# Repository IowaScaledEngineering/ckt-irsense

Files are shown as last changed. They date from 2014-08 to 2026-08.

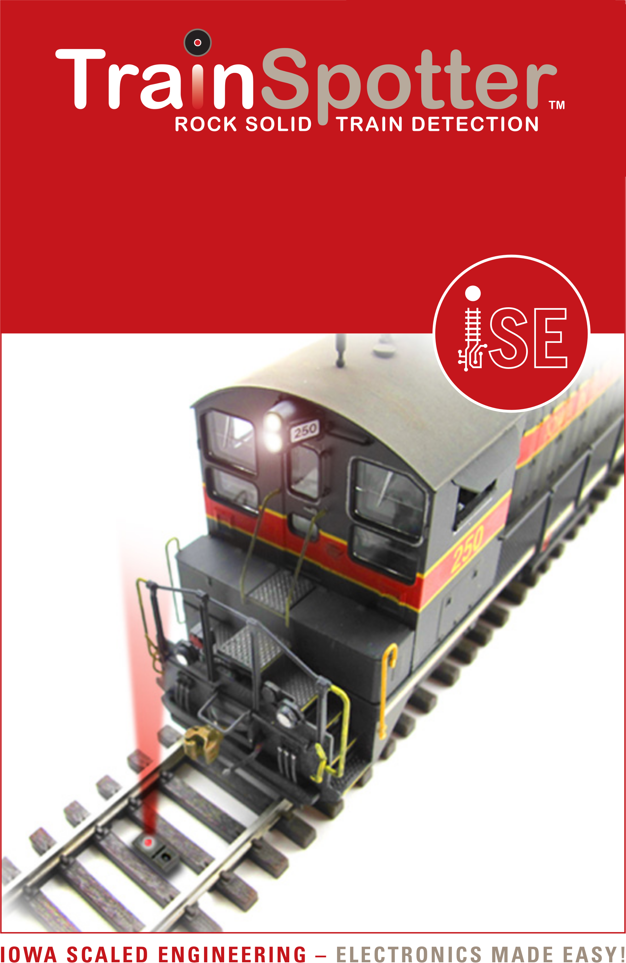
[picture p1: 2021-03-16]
doc/insert/irsense-insert.png

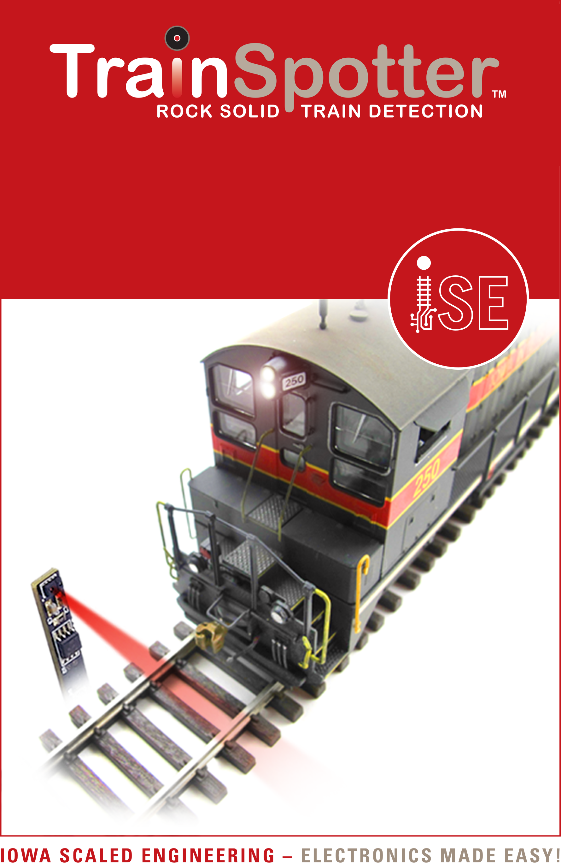
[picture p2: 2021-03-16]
doc/insert/irsense-insert-ra.png

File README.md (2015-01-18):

This is the software library, example applications, and hardware design files for the Iowa Scaled Engineering CKT-IRSENSE Reflective Infrared Proximity Sensor

The product can be found at:
http://www.iascaled.com/store/CKT-IRSENSE

Hardware use documentation (the manual) can be found in the /doc/ directory.

Like all public Iowa Scaled Engineering designs, the CKT-IRSENSE is both open hardware and open source software.  Please refer to the hardware and software license files in this repository for details.

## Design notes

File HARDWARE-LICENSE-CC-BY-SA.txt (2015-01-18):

The hardware design files for the Iowa Scaled Engineering CKT-IRSENSE are
open hardware, and licensed under the Creative Commons Attribution-Share
Alike license.

A copy can be found below, or from 
  http://creativecommons.org/licenses/by-sa/4.0/legalcode
-----------------------------------------------------------------------------

Creative Commons Attribution-ShareAlike 4.0 International Public License

By exercising the Licensed Rights (defined below), You accept and agree to
be bound by the terms and conditions of this Creative Commons
Attribution-ShareAlike 4.0 International Public License ("Public License").
To the extent this Public License may be interpreted as a contract, You are
granted the Licensed Rights in consideration of Your acceptance of these
terms and conditions, and the Licensor grants You such rights in
consideration of benefits the Licensor receives from making the Licensed
Material available under these terms and conditions.

Section 1 – Definitions.

    Adapted Material means material subject to Copyright and Similar Rights
that is derived from or based upon the Licensed Material and in which the
Licensed Material is translated, altered, arranged, transformed, or
otherwise modified in a manner requiring permission under the Copyright and
Similar Rights held by the Licensor. For purposes of this Public License,
where the Licensed Material is a musical work, performance, or sound
recording, Adapted Material is always produced where the Licensed Material
is synched in timed relation with a moving image.
    Adapter's License means the license You apply to Your Copyright and
Similar Rights in Your contributions to Adapted Material in accordance with
the terms and conditions of this Public License.
    BY-SA Compatible License means a license listed at
creativecommons.org/compatiblelicenses, approved by Creative Commons as
essentially the equivalent of this Public License.
    Copyright and Similar Rights means copyright and/or similar rights
closely related to copyright including, without limitation, performance,
broadcast, sound recording, and Sui Generis Database Rights, without regard
to how the rights are labeled or categorized. For purposes of this Public
License, the rights specified in Section 2(b)(1)-(2) are not Copyright and
Similar Rights.
    Effective Technological Measures means those measures that, in the
absence of proper authority, may not be circumvented under laws fulfilling
obligations under Article 11 of the WIPO Copyright Treaty adopted on
December 20, 1996, and/or similar international agreements.
    Exceptions and Limitations means fair use, fair dealing, and/or any
other exception or limitation to Copyright and Similar Rights that applies
to Your use of the Licensed Material.
    License Elements means the license attributes listed in the name of a
Creative Commons Public License. The License Elements of this Public License
are Attribution and ShareAlike.
    Licensed Material means the artistic or literary work, database, or
other material to which the Licensor applied this Public License.
    Licensed Rights means the rights granted to You subject to the terms and
conditions of this Public License, which are limited to all Copyright and
Similar Rights that apply to Your use of the Licensed Material and that the
Licensor has authority to license.
    Licensor means the individual(s) or entity(ies) granting rights under
this Public License.
    Share means to provide material to the public by any means or process
that requires permission under the Licensed Rights, such as reproduction,
public display, public performance, distribution, dissemination,
communication, or importation, and to make material available to the public
including in ways that members of the public may access the material from a
place and at a time individually chosen by them.
    Sui Generis Database Rights means rights other than copyright resulting
from Directive 96/9/EC of the European Parliament and of the Council of 11
March 1996 on the legal protection of databases, as amended and/or
succeeded, as well as other essentially equivalent rights anywhere in the
world.
    You means the individual or entity exercising the Licensed Rights under
this Public License. Your has a corresponding meaning.

Section 2 – Scope.

    License grant.
        Subject to the terms and conditions of this Public License, the
Licensor hereby grants You a worldwide, royalty-free, non-sublicensable,
non-exclusive, irrevocable license to exercise the Licensed Rights in the
Licensed Material to:
            reproduce and Share the Licensed Material, in whole or in part;
and
            produce, reproduce, and Share Adapted Material.
        Exceptions and Limitations. For the avoidance of doubt, where
Exceptions and Limitations apply to Your use, this Public License does not
apply, and You do not need to comply with its terms and conditions.
        Term. The term of this Public License is specified in Section 6(a).
        Media and formats; technical modifications allowed. The Licensor
authorizes You to exercise the Licensed Rights in all media and formats
whether now known or hereafter created, and to make technical modifications
necessary to do so. The Licensor waives and/or agrees not to assert any
right or authority to forbid You from making technical modifications
necessary to exercise the Licensed Rights, including technical modifications
necessary to circumvent Effective Technological Measures. For purposes of
this Public License, simply making modifications authorized by this Section
2(a)(4) never produces Adapted Material.
        Downstream recipients.
            Offer from the Licensor – Licensed Material. Every recipient of
the Licensed Material automatically receives an offer from the Licensor to
exercise the Licensed Rights under the terms and conditions of this Public
License.
            Additional offer from the Licensor – Adapted Material. Every
recipient of Adapted Material from You automatically receives an offer from
the Licensor to exercise the Licensed Rights in the Adapted Material under
the conditions of the Adapter’s License You apply.
            No downstream restrictions. You may not offer or impose any
additional or different terms or conditions on, or apply any Effective
Technological Measures to, the Licensed Material if doing so restricts
exercise of the Licensed Rights by any recipient of the Licensed Material.
        No endorsement. Nothing in this Public License constitutes or may be
construed as permission to assert or imply that You are, or that Your use of
the Licensed Material is, connected with, or sponsored, endorsed, or granted
official status by, the Licensor or others designated to receive attribution
as provided in Section 3(a)(1)(A)(i).

    Other rights.
        Moral rights, such as the right of integrity, are not licensed under
this Public License, nor are publicity, privacy, and/or other similar
personality rights; however, to the extent possible, the Licensor waives
and/or agrees not to assert any such rights held by the Licensor to the
limited extent necessary to allow You to exercise the Licensed Rights, but
not otherwise.
        Patent and trademark rights are not licensed under this Public
License.
        To the extent possible, the Licensor waives any right to collect
royalties from You for the exercise of the Licensed Rights, whether directly
or through a collecting society under any voluntary or waivable statutory or
compulsory licensing scheme. In all other cases the Licensor expressly
reserves any right to collect such royalties.

Section 3 – License Conditions.

Your exercise of the Licensed Rights is expressly made subject to the
following conditions.

    Attribution.

        If You Share the Licensed Material (including in modified form), You
must:
            retain the following if it is supplied by the Licensor with the
Licensed Material:
                identification of the creator(s) of the Licensed Material
and any others designated to receive attribution, in any reasonable manner
requested by the Licensor (including by pseudonym if designated);
                a copyright notice;
                a notice that refers to this Public License;
                a notice that refers to the disclaimer of warranties;
                a URI or hyperlink to the Licensed Material to the extent
                reasonably practicable;
            indicate if You modified the Licensed Material and retain an
indication of any previous modifications; and
            indicate the Licensed Material is licensed under this Public
License, and include the text of, or the URI or hyperlink to, this Public
License.
        You may satisfy the conditions in Section 3(a)(1) in any reasonable
manner based on the medium, means, and context in which You Share the
Licensed Material. For example, it may be reasonable to satisfy the
conditions by providing a URI or hyperlink to a resource that includes the
required information.
        If requested by the Licensor, You must remove any of the information
required by Section 3(a)(1)(A) to the extent reasonably practicable.
    ShareAlike.

    In addition to the conditions in Section 3(a), if You Share Adapted
Material You produce, the following conditions also apply.
        The Adapter’s License You apply must be a Creative Commons license
with the same License Elements, this version or later, or a BY-SA Compatible
License.
        You must include the text of, or the URI or hyperlink to, the
Adapter's License You apply. You may satisfy this condition in any
reasonable manner based on the medium, means, and context in which You Share
Adapted Material.
        You may not offer or impose any additional or different terms or
conditions on, or apply any Effective Technological Measures to, Adapted
Material that restrict exercise of the rights granted under the Adapter's
License You apply.

Section 4 – Sui Generis Database Rights.

Where the Licensed Rights include Sui Generis Database Rights that apply to
Your use of the Licensed Material:

    for the avoidance of doubt, Section 2(a)(1) grants You the right to
extract, reuse, reproduce, and Share all or a substantial portion of the
contents of the database;
    if You include all or a substantial portion of the database contents in
a database in which You have Sui Generis Database Rights, then the database
in which You have Sui Generis Database Rights (but not its individual
contents) is Adapted Material, including for purposes of Section 3(b); and
    You must comply with the conditions in Section 3(a) if You Share all or
a substantial portion of the contents of the database.

For the avoidance of doubt, this Section 4 supplements and does not replace
Your obligations under this Public License where the Licensed Rights include
other Copyright and Similar Rights.

Section 5 – Disclaimer of Warranties and Limitation of Liability.

    Unless otherwise separately undertaken by the Licensor, to the extent
possible, the Licensor offers the Licensed Material as-is and as-available,
and makes no representations or warranties of any kind concerning the
Licensed Material, whether express, implied, statutory, or other. This
includes, without limitation, warranties of title, merchantability, fitness
for a particular purpose, non-infringement, absence of latent or other
defects, accuracy, or the presence or absence of errors, whether or not
known or discoverable. Where disclaimers of warranties are not allowed in
full or in part, this disclaimer may not apply to You.
    To the extent possible, in no event will the Licensor be liable to You
on any legal theory (including, without limitation, negligence) or otherwise
for any direct, special, indirect, incidental, consequential, punitive,
exemplary, or other losses, costs, expenses, or damages arising out of this
Public License or use of the Licensed Material, even if the Licensor has
been advised of the possibility of such losses, costs, expenses, or damages.
Where a limitation of liability is not allowed in full or in part, this
limitation may not apply to You.

    The disclaimer of warranties and limitation of liability provided above
shall be interpreted in a manner that, to the extent possible, most closely
approximates an absolute disclaimer and waiver of all liability.

Section 6 – Term and Termination.

    This Public License applies for the term of the Copyright and Similar
Rights licensed here. However, if You fail to comply with this Public
License, then Your rights under this Public License terminate automatically.

    Where Your right to use the Licensed Material has terminated under
Section 6(a), it reinstates:
        automatically as of the date the violation is cured, provided it is
cured within 30 days of Your discovery of the violation; or
        upon express reinstatement by the Licensor.
    For the avoidance of doubt, this Section 6(b) does not affect any right
the Licensor may have to seek remedies for Your violations of this Public
License.
    For the avoidance of doubt, the Licensor may also offer the Licensed
Material under separate terms or conditions or stop distributing the
Licensed Material at any time; however, doing so will not terminate this
Public License.
    Sections 1, 5, 6, 7, and 8 survive termination of this Public License.

Section 7 – Other Terms and Conditions.

    The Licensor shall not be bound by any additional or different terms or
conditions communicated by You unless expressly agreed.
    Any arrangements, understandings, or agreements regarding the Licensed
Material not stated herein are separate from and independent of the terms
and conditions of this Public License.

Section 8 – Interpretation.

    For the avoidance of doubt, this Public License does not, and shall not
be interpreted to, reduce, limit, restrict, or impose conditions on any use
of the Licensed Material that could lawfully be made without permission
under this Public License.
    To the extent possible, if any provision of this Public License is
deemed unenforceable, it shall be automatically reformed to the minimum
extent necessary to make it enforceable. If the provision cannot be
reformed, it shall be severed from this Public License without affecting the
enforceability of the remaining terms and conditions.
    No term or condition of this Public License will be waived and no
failure to comply consented to unless expressly agreed to by the Licensor.
    Nothing in this Public License constitutes or may be interpreted as a
limitation upon, or waiver of, any privileges and immunities that apply to
the Licensor or You, including from the legal processes of any jurisdiction
or authority.

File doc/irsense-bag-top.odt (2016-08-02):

Iowa Scaled Engineering, LLC

http://iascaled.com/

Iowa Scaled Engineering, LLC

http://iascaled.com/

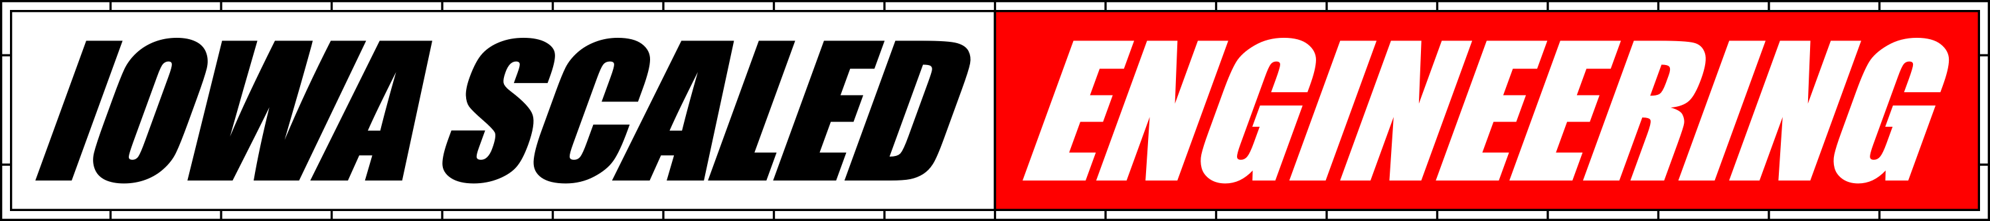
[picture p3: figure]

Reflective Infrared Proximity Sensor

The CKT-IRSENSE is an inexpensive reflective infrared proximity sensor, designed primarily for model railroad use, utilizing the latest in proximity sensor technology. It can be used to trigger a variety of sound and visual effects as well as provide track occupancy status.

CKT-IRSENSE

Reflective Infrared Proximity Sensor

The CKT-IRSENSE-2PC is an inexpensive reflective infrared proximity sensor, designed primarily for model railroad use, utilizing the latest in proximity sensor technology. It can be used to trigger a variety of sound and visual effects as well as provide track occupancy status. The sensor is connected via 4-conductor flat wire cable to the control board allowing greater flexibility in mounting the sensor.

CKT-IRSENSE-2PC

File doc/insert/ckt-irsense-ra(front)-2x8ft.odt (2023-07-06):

Reflective Infrared Proximity Sensor with Right-Angle Sensor

www.iascaled.com

2x CKT-IRSENSE-RA

With 8’ cables

Reflective Infrared Proximity Sensor with Right-Angle Sensor

www.iascaled.com

2x CKT-IRSENSE-RA

With 8’ cables

Reflective Infrared Proximity Sensor with Right-Angle Sensor

www.iascaled.com

2x CKT-IRSENSE-RA

With 8’ cables

Reflective Infrared Proximity Sensor with Right-Angle Sensor

www.iascaled.com

2x CKT-IRSENSE-RA

With 8’ cables

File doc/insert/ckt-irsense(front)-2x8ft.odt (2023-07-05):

Reflective Infrared Proximity Sensor

www.iascaled.com

2x CKT-IRSENSE

With 8’ cables

Reflective Infrared Proximity Sensor

www.iascaled.com

2x CKT-IRSENSE

With 8’ cables

Reflective Infrared Proximity Sensor

www.iascaled.com

2x CKT-IRSENSE

With 8’ cables

Reflective Infrared Proximity Sensor

www.iascaled.com

2x CKT-IRSENSE

With 8’ cables

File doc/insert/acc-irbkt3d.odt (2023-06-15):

IR Sensor Mounting Bracket Kit

www.iascaled.com

ACC-IRBKT3D

$4.00

IR Sensor Mounting Bracket Kit

www.iascaled.com

ACC-IRBKT3D

$4.00

IR Sensor Mounting Bracket Kit

www.iascaled.com

ACC-IRBKT3D

$4.00

IR Sensor Mounting Bracket Kit

www.iascaled.com

ACC-IRBKT3D

$4.00

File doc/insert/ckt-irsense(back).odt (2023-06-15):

The TrainSpotter is a simple infrared proximity sensor that makes detection of model railroad locomotives and rolling stock easy and reliable. Just place the sensor where its invisible light beam will reflect off the object of interest and you’re done – no time-consuming or frustrating adjustments! Based on modern silicon technology, this sensor is tolerant of ambient (background) lighting conditions, be it completely dark or under full lights, with no false triggering. With a discrete under-track installation, this low-profile sensor solves many of the challenges that plague other optical detector products.

Typical Applications

● Activate grade crossing signals

● Trigger sounds

● Build an automatic interchange

● Indicate end-of-track in hidden staging yards

● Detect block occupancy for signal systems

The TrainSpotter is a simple infrared proximity sensor that makes detection of model railroad locomotives and rolling stock easy and reliable. Just place the sensor where its invisible light beam will reflect off the object of interest and you’re done – no time-consuming or frustrating adjustments! Based on modern silicon technology, this sensor is tolerant of ambient (background) lighting conditions, be it completely dark or under full lights, with no false triggering. With a discrete under-track installation, this low-profile sensor solves many of the challenges that plague other optical detector products.

Typical Applications

● Activate grade crossing signals

● Trigger sounds

● Build an automatic interchange

● Indicate end-of-track in hidden staging yards

● Detect block occupancy for signal systems

The TrainSpotter is a simple infrared proximity sensor that makes detection of model railroad locomotives and rolling stock easy and reliable. Just place the sensor where its invisible light beam will reflect off the object of interest and you’re done – no time-consuming or frustrating adjustments! Based on modern silicon technology, this sensor is tolerant of ambient (background) lighting conditions, be it completely dark or under full lights, with no false triggering. With a discrete under-track installation, this low-profile sensor solves many of the challenges that plague other optical detector products.

Typical Applications

● Activate grade crossing signals

● Trigger sounds

● Build an automatic interchange

● Indicate end-of-track in hidden staging yards

● Detect block occupancy for signal systems

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

Typical Applications

● Activate grade crossing signals

● Trigger sounds

● Build an automatic interchange

● Indicate end-of-track in hidden staging yards

● Detect block occupancy for signal systems

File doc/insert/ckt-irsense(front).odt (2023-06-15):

Reflective Infrared Proximity Sensor

www.iascaled.com

CKT-IRSENSE

$19.00

Reflective Infrared Proximity Sensor

www.iascaled.com

CKT-IRSENSE

$19.00

Reflective Infrared Proximity Sensor

www.iascaled.com

CKT-IRSENSE

$19.00

Reflective Infrared Proximity Sensor

www.iascaled.com

CKT-IRSENSE

$19.00

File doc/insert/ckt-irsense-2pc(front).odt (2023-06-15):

Reflective Infrared Proximity Sensor with Remote Sensor

www.iascaled.com

CKT-IRSENSE-2PC

$25.00

Reflective Infrared Proximity Sensor with Remote Sensor

www.iascaled.com

CKT-IRSENSE-2PC

$25.00

Reflective Infrared Proximity Sensor with Remote Sensor

www.iascaled.com

CKT-IRSENSE-2PC

$25.00

Reflective Infrared Proximity Sensor with Remote Sensor

www.iascaled.com

CKT-IRSENSE-2PC

$25.00

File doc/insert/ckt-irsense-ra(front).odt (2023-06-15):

Reflective Infrared Proximity Sensor with Right-Angle Sensor

www.iascaled.com

CKT-IRSENSE-RA

$19.00

Reflective Infrared Proximity Sensor with Right-Angle Sensor

www.iascaled.com

CKT-IRSENSE-RA

$19.00

Reflective Infrared Proximity Sensor with Right-Angle Sensor

www.iascaled.com

CKT-IRSENSE-RA

$19.00

Reflective Infrared Proximity Sensor with Right-Angle Sensor

www.iascaled.com

CKT-IRSENSE-RA

$19.00

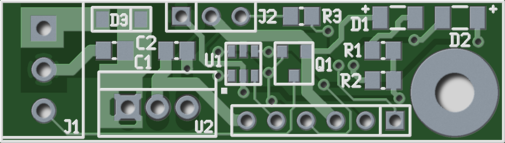
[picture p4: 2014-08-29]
doc/applications/spring-switch/mrservo.png

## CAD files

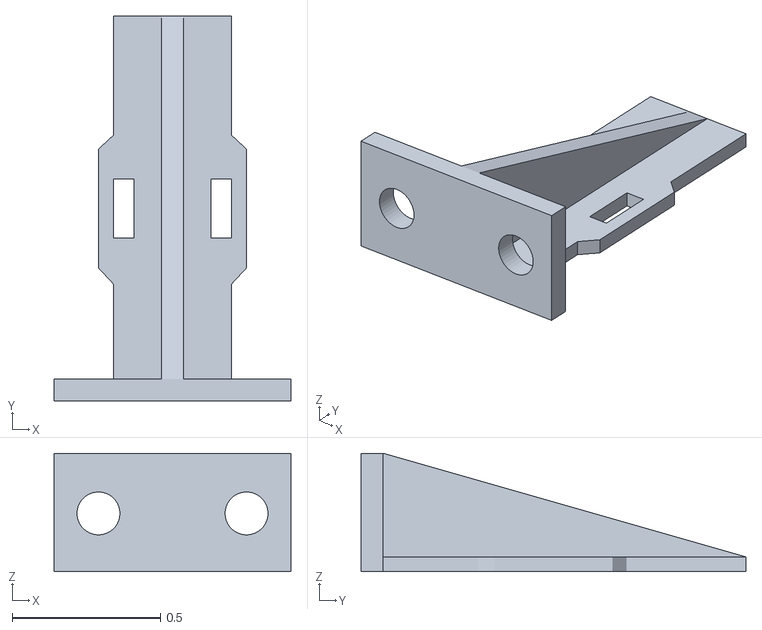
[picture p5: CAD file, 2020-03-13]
mech/irsense-bracket/irsense-bracket v2.stl
0.8 x 1.30 x 0.4

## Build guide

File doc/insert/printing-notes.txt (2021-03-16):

IRSENSE INSERT
--------------
Print settings (M475):
- Print PDF from Acrobat
- Use "Photo (sRGB)" color theme

Print Settings (8210)
- Print from libreoffice
- Maximum DPI
- HP Brochure Matte 180g
- Default (sRGB)

10/25/2020: "Yellowed" images to get better color rendition on printer
10/30/2020: Reverted to original images

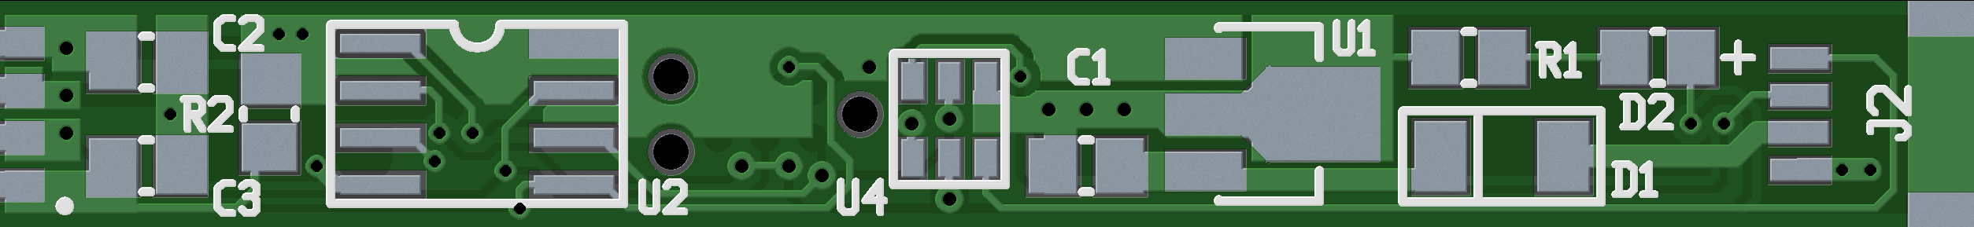
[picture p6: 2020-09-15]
doc/usermanual/ckt-irsense-front.png

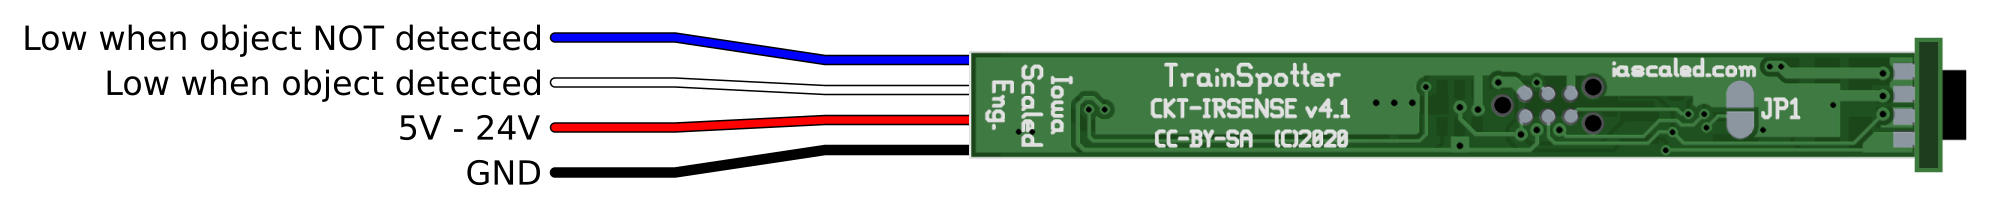
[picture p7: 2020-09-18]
doc/usermanual/usermanual.png

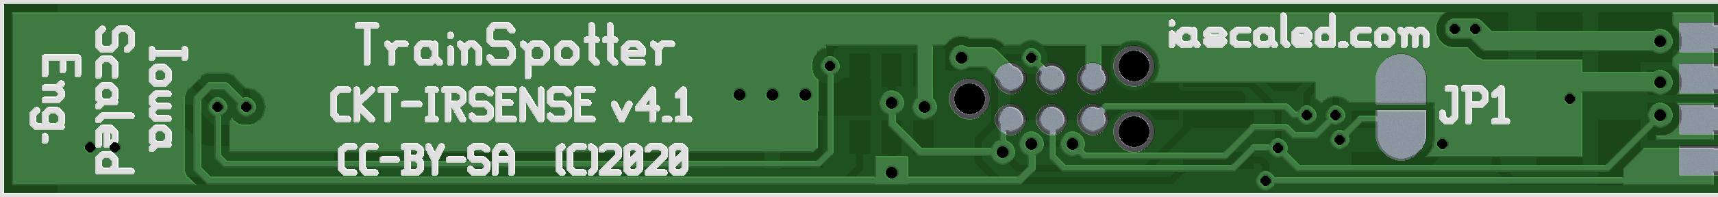
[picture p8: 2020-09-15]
doc/usermanual/ckt-irsense-back.png

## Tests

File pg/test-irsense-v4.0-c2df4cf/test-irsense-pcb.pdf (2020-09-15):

# test-irsense.pcb

# 1. Table of Contents (This Page) Created on Wed Aug 19 21:00:15 2020

# 2. top 3. bottom 4. plated-drill 5. componentmask 6. soldermask 7. topsilk 8. bottomsilk 9. toppaste 10. topassembly 11. bottomassembly 12. fab

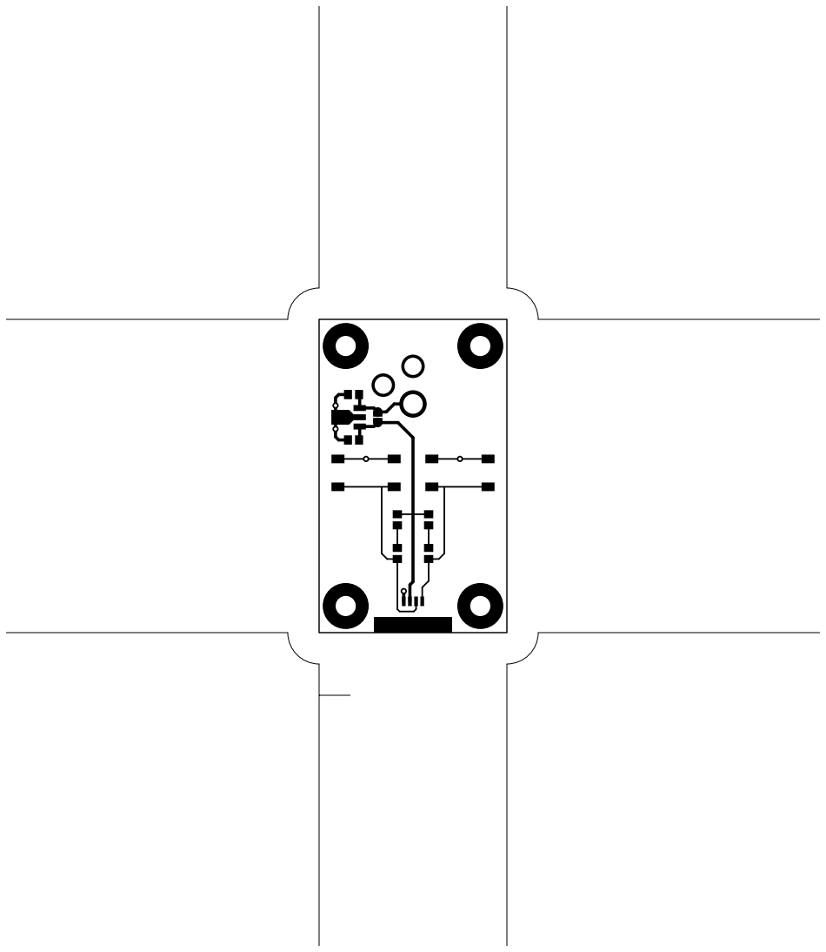
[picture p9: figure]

top, scale = 1:1.000

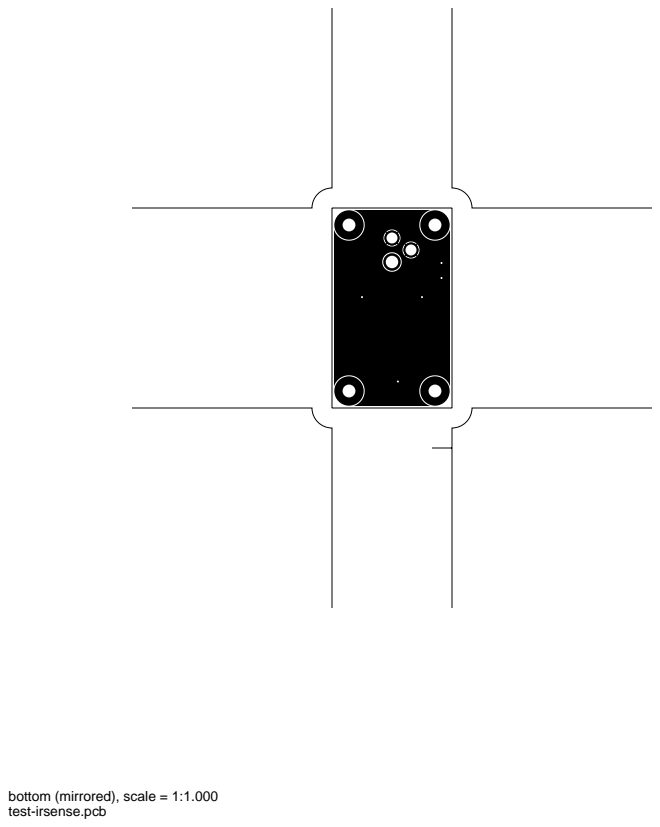
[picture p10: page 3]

bottom (mirrored), scale = 1:1.000

plated-drill, scale = 1:1.000

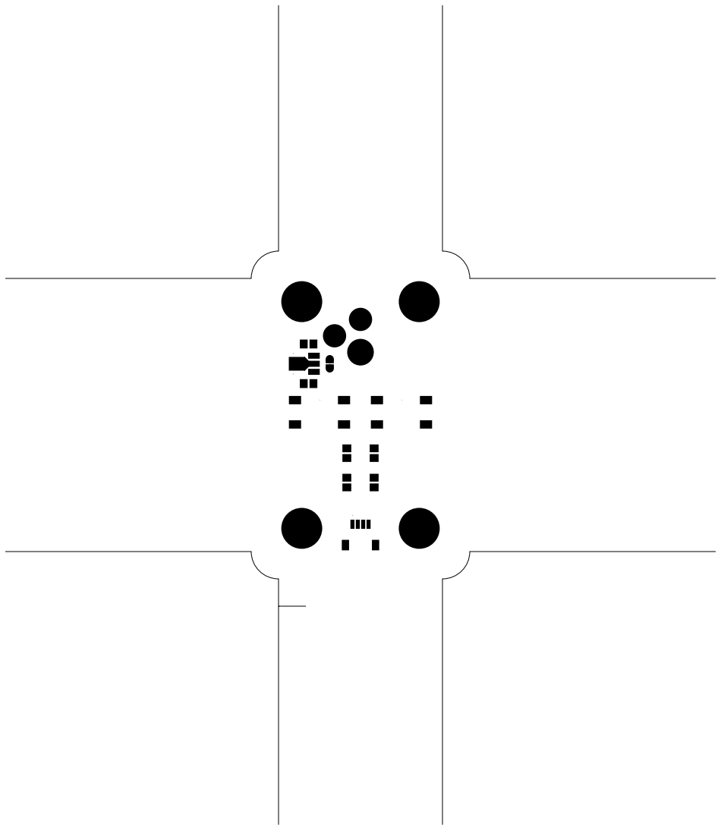
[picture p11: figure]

topmask, scale = 1:1.000

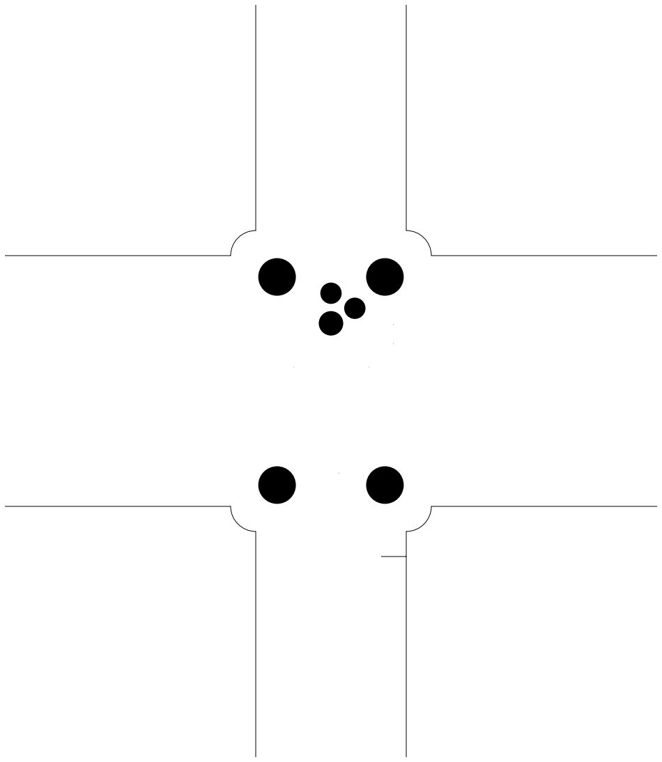
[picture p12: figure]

bottommask (mirrored), scale = 1:1.000

topsilk, scale = 1:1.000 bottomsilk (mirrored), scale = 1:1.000

toppaste, scale = 1:1.000

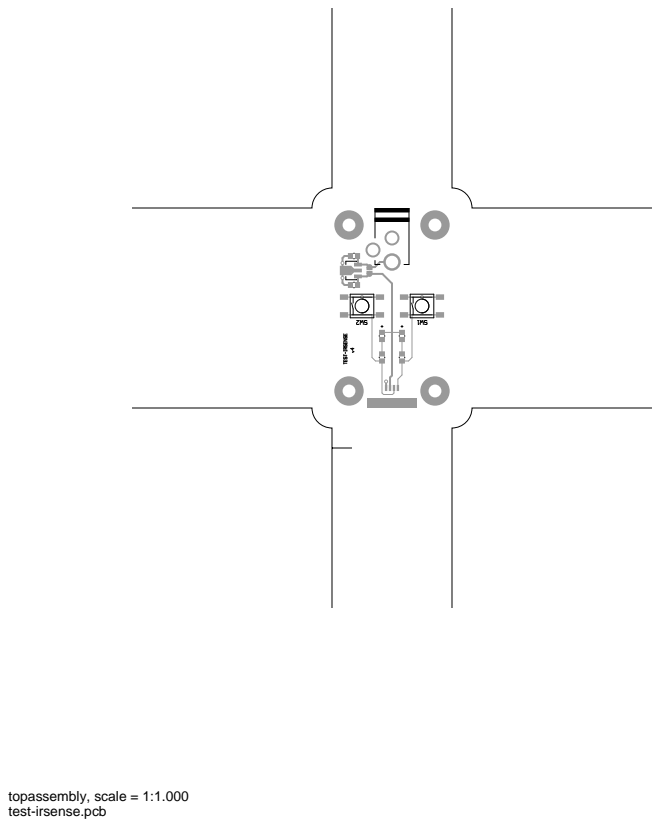
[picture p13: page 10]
topassembly, scale = 1:1.000

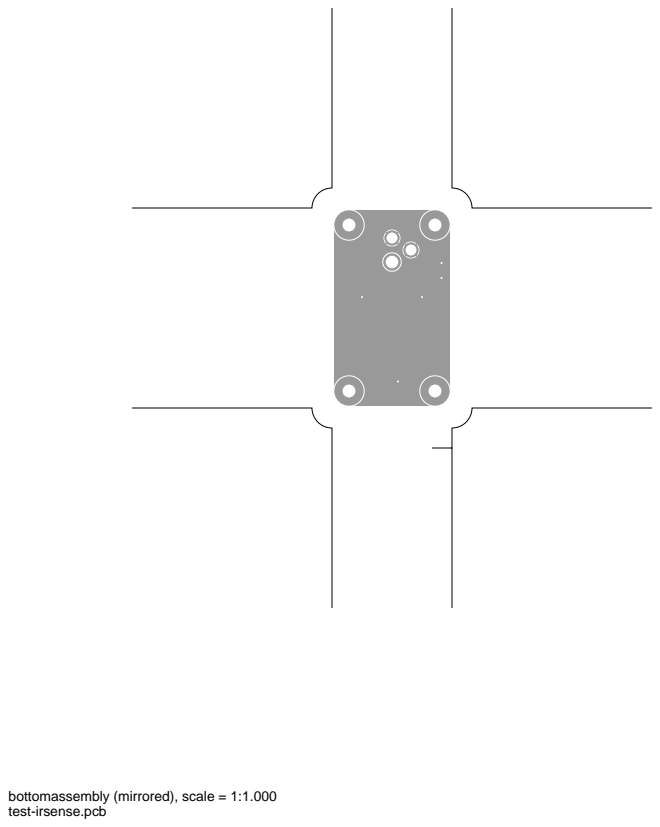
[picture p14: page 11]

bottomassembly (mirrored), scale = 1:1.000

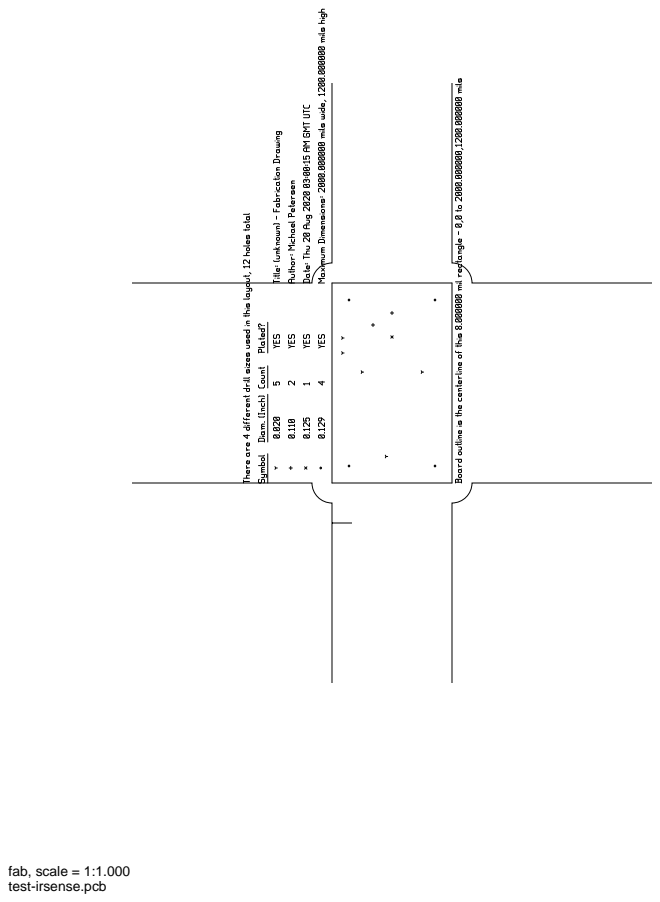
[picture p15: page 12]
fab, scale = 1:1.000

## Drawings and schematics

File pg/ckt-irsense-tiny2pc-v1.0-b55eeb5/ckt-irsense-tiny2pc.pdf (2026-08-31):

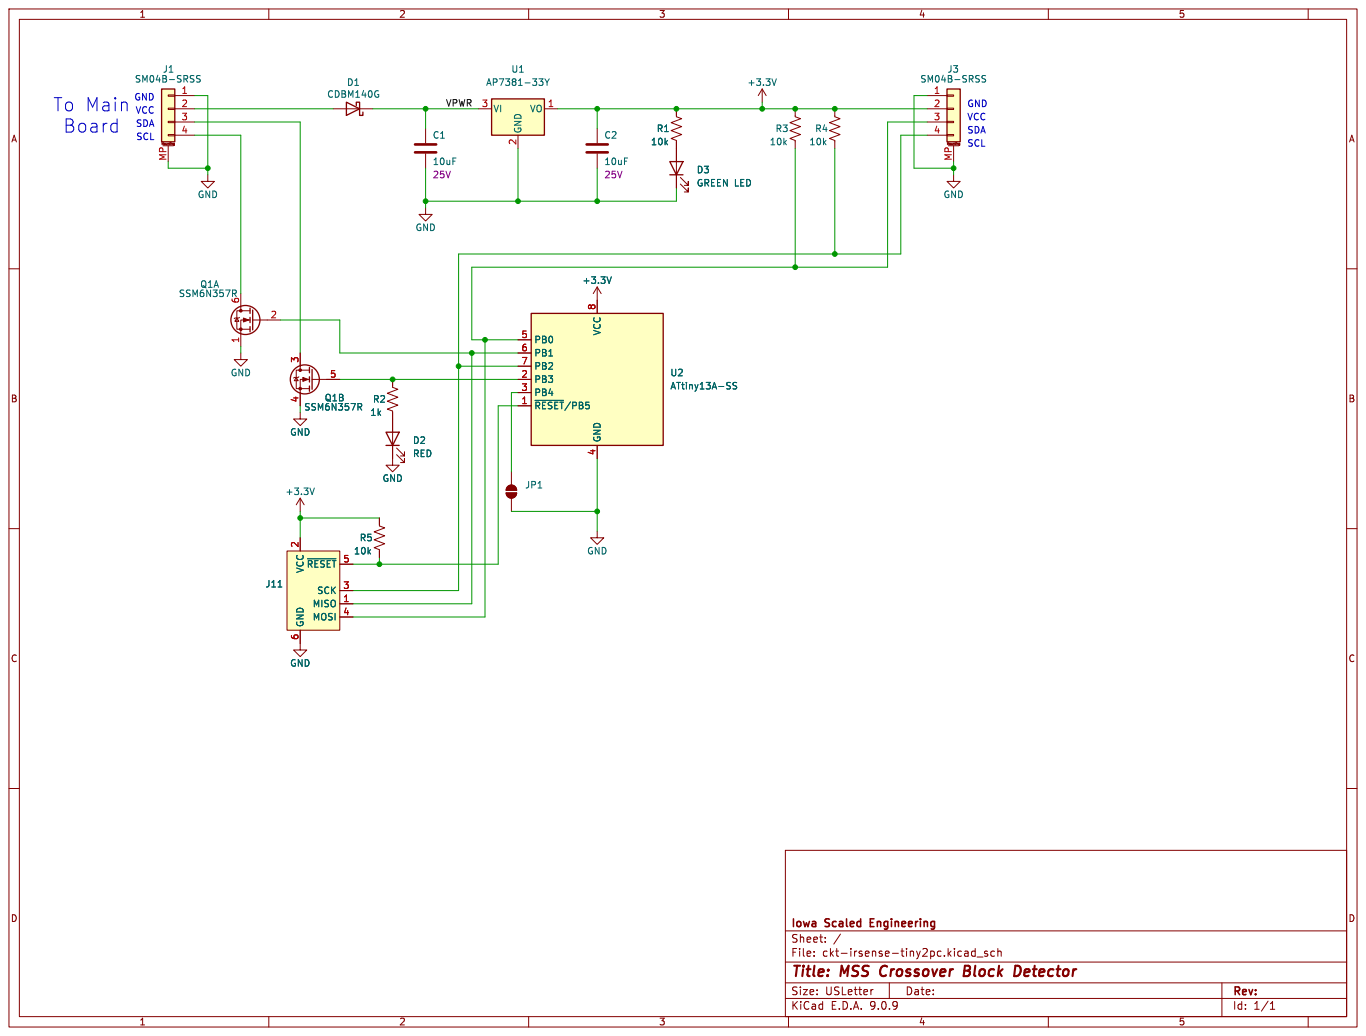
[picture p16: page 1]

3 4 D2 RED GND GND GND

6 ~{RESET}5 SCK 3 MISO 1 MOSI 4

Id: 1/1 Title: MSS Crossover Block Detector File: ckt-irsense-tiny2pc.kicad_sch Sheet: /

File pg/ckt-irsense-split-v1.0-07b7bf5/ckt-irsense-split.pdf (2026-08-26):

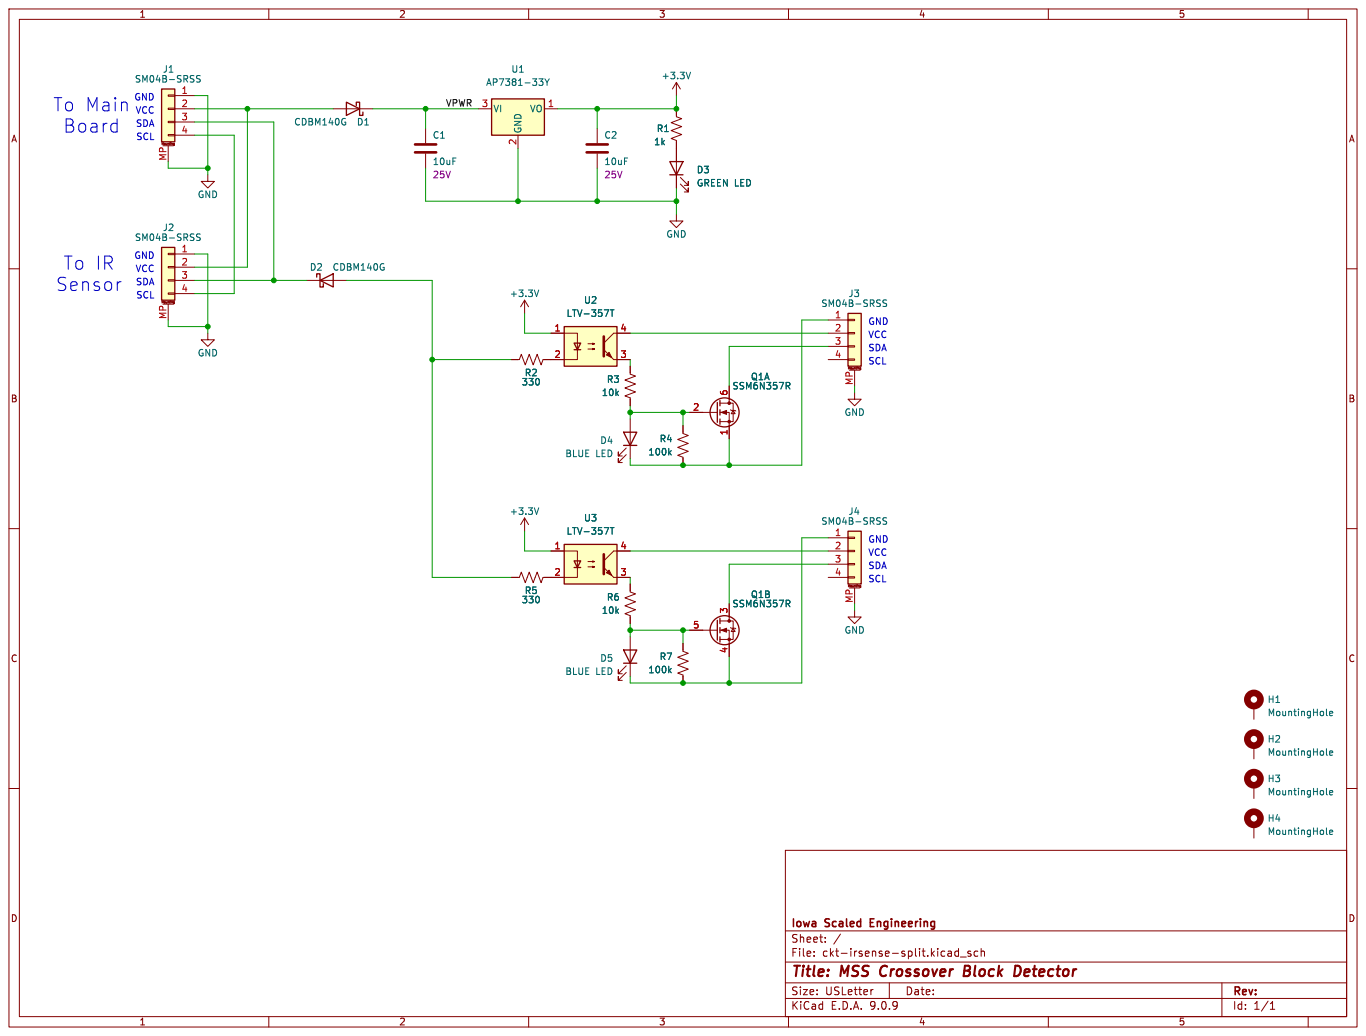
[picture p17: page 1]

SCL To Main VCC Board

H4 MountingHole H2 MountingHole H3 MountingHole H1 MountingHole

Id: 1/1 Title: MSS Crossover Block Detector File: ckt-irsense-split.kicad_sch Sheet: /

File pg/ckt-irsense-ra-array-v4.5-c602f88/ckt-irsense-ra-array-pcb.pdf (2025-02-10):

## ckt-irsense-ra-array.pcb

## 1. Table of Contents (This Page) Created on Sun Feb 9 21:01:32 2025 2. top 3. bottom 4. outline 5. plated-drill 6. unplated-drill 7. componentmask 8. soldermask 9. topsilk 10. bottomsilk 11. toppaste 12. bottompaste 13. topassembly 14. bottomassembly 15. fab

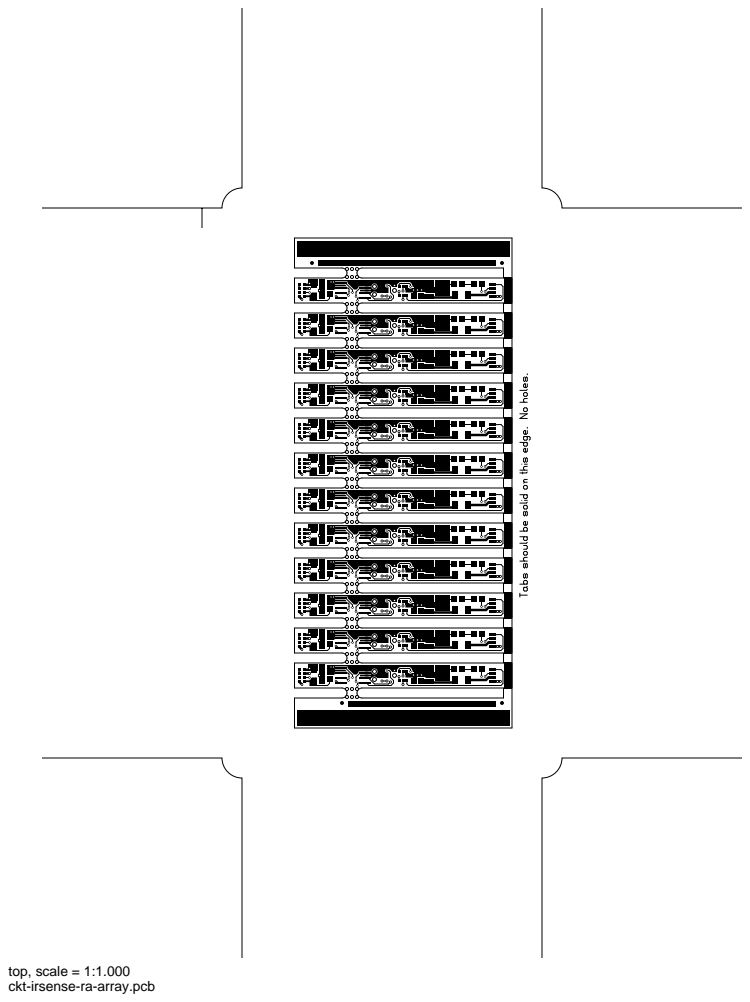
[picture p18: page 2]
top, scale = 1:1.000

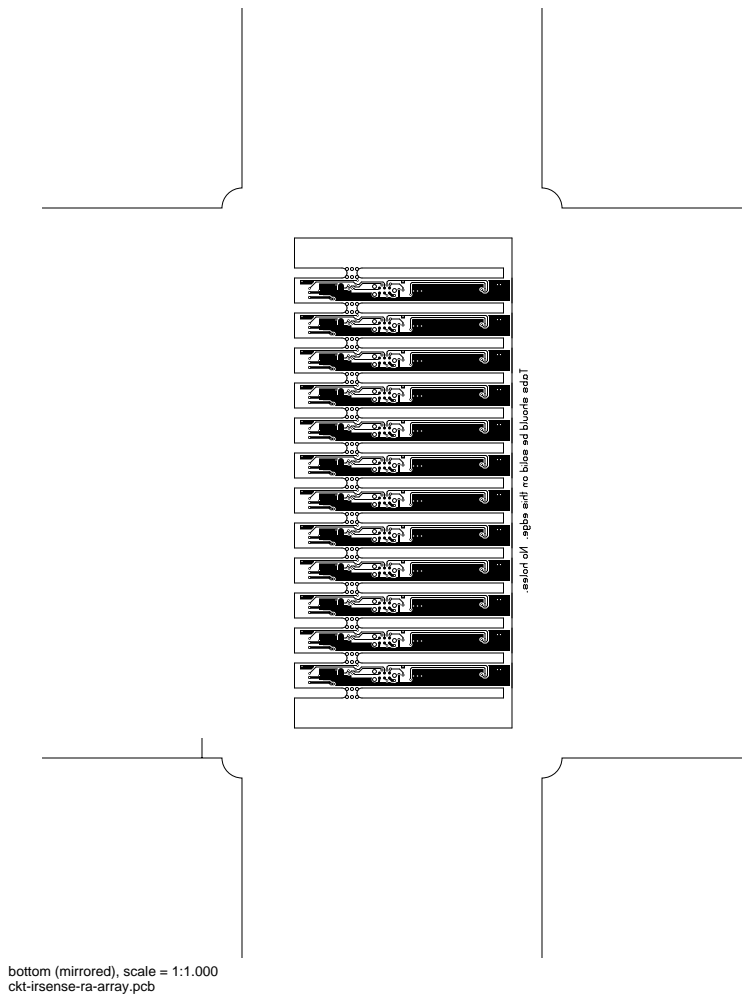
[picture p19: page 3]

bottom (mirrored), scale = 1:1.000

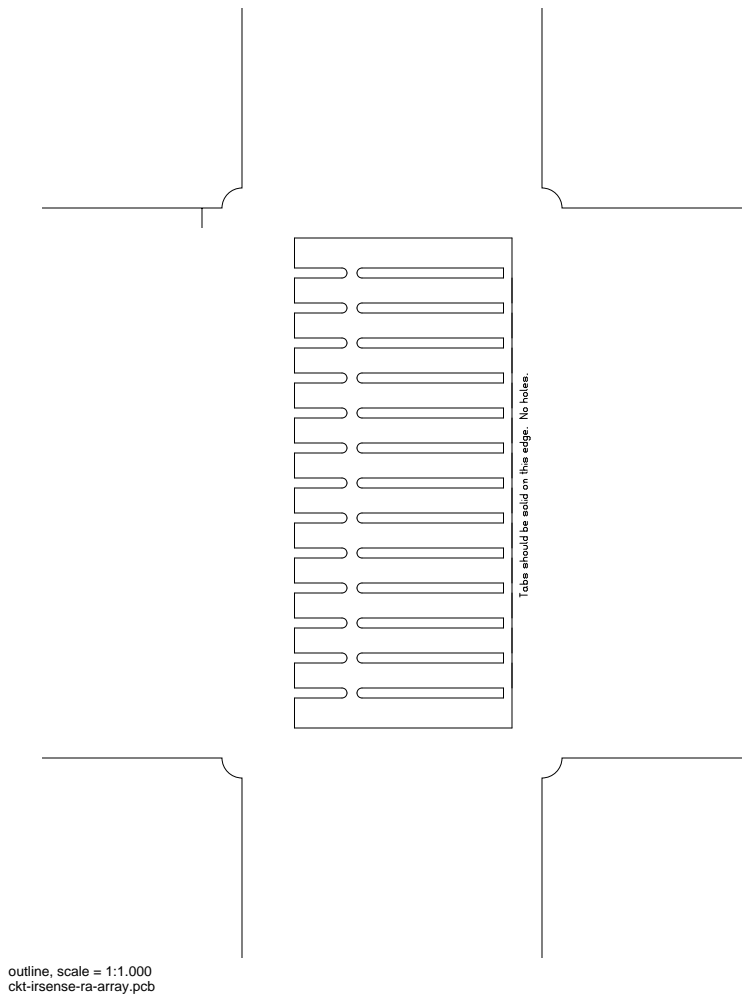
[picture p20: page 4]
outline, scale = 1:1.000

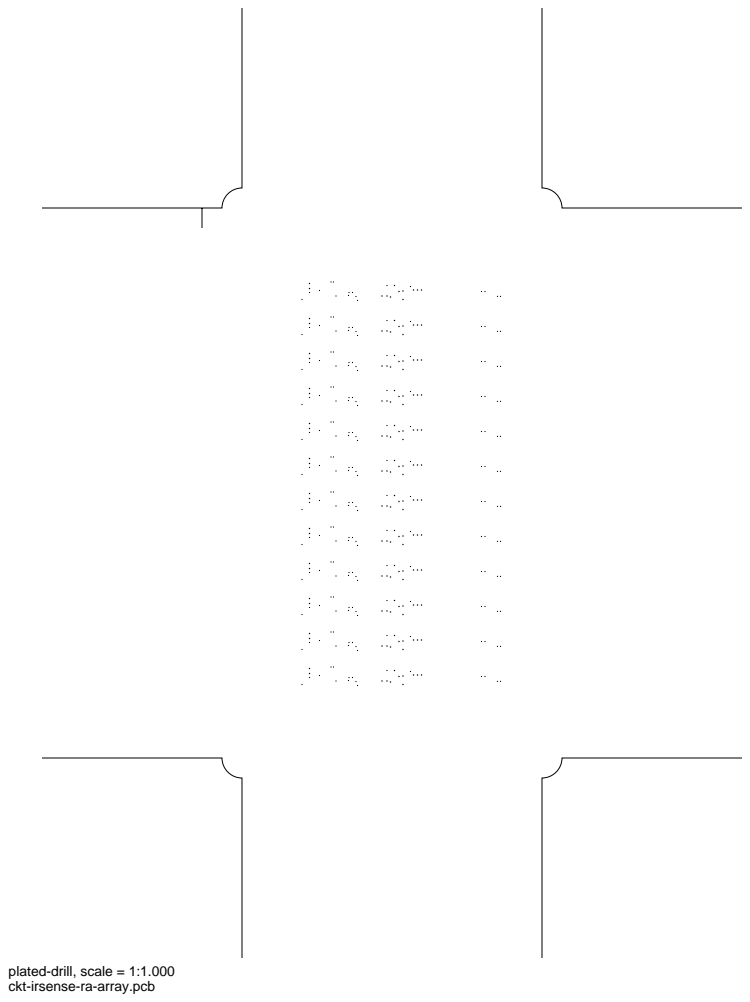
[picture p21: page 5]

plated-drill, scale = 1:1.000

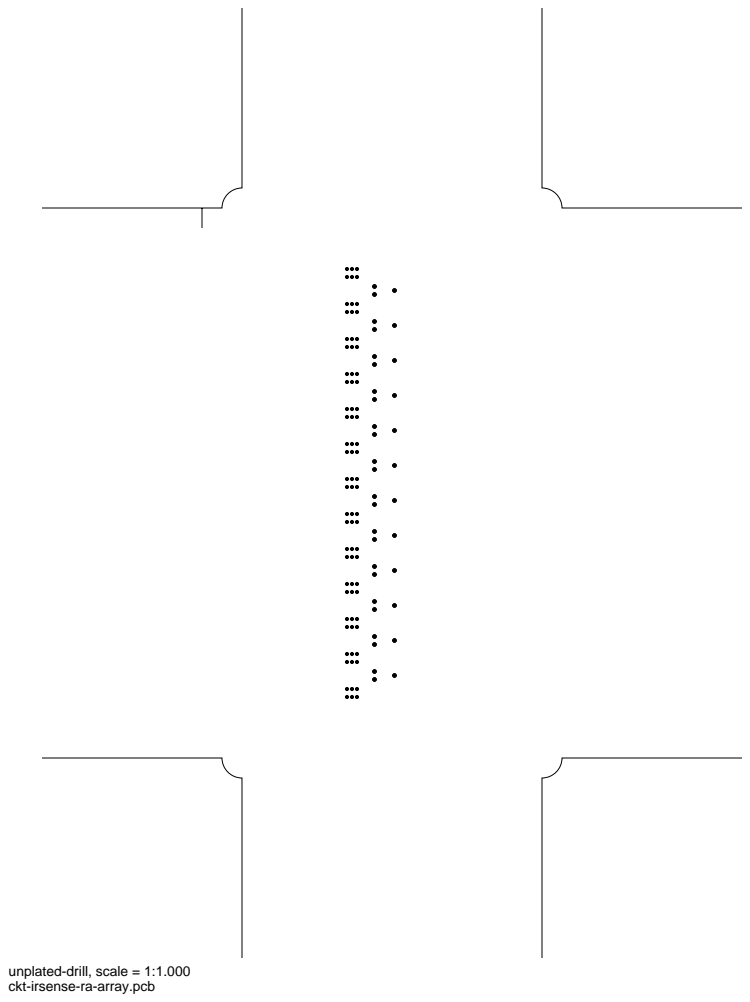
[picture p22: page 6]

unplated-drill, scale = 1:1.000

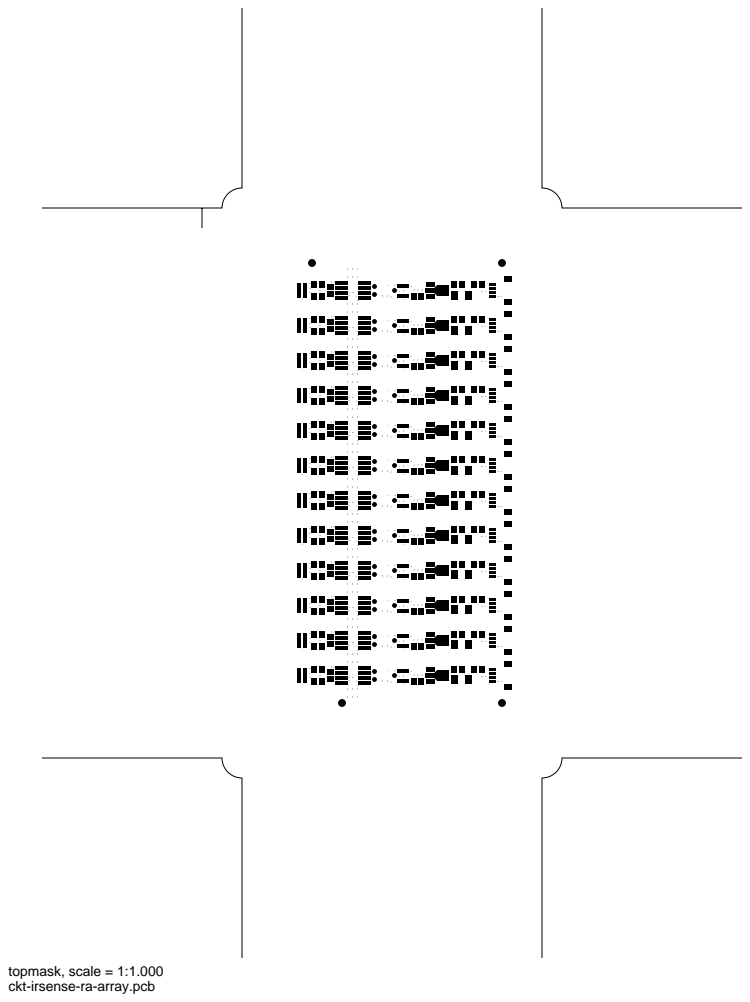
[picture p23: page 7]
topmask, scale = 1:1.000

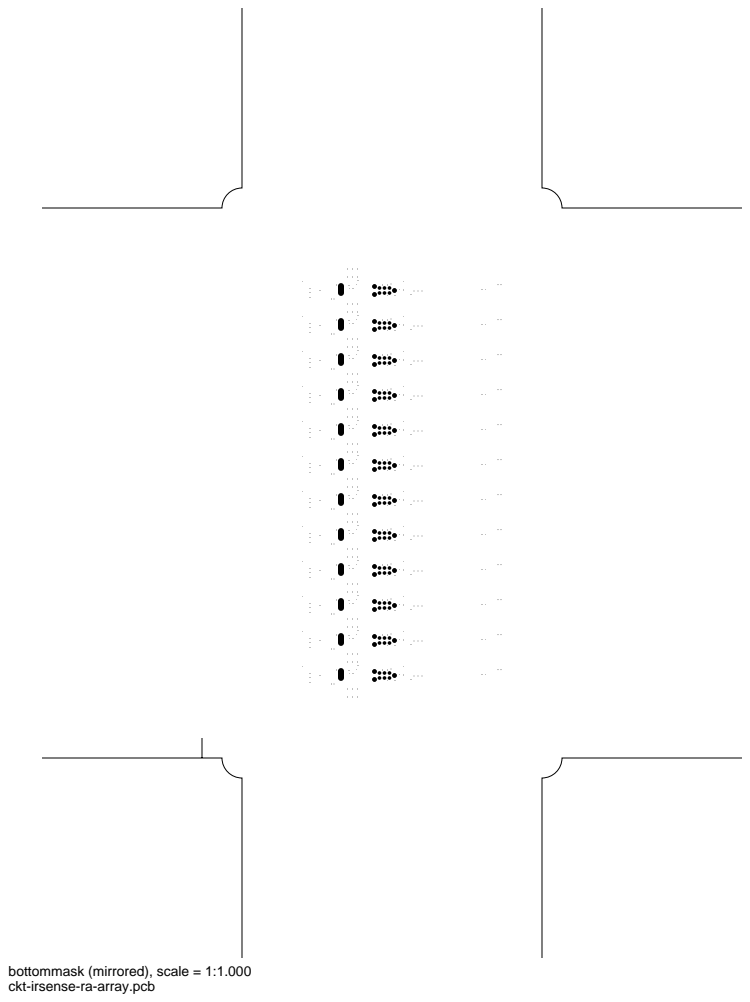
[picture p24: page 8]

bottommask (mirrored), scale = 1:1.000

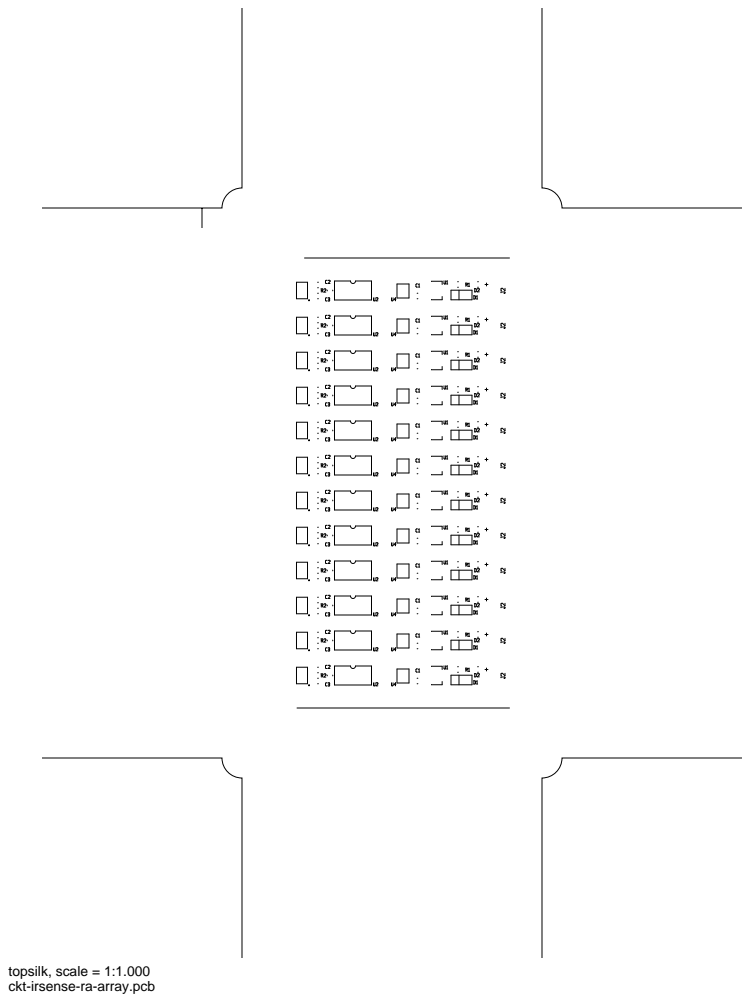
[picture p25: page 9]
topsilk, scale = 1:1.000

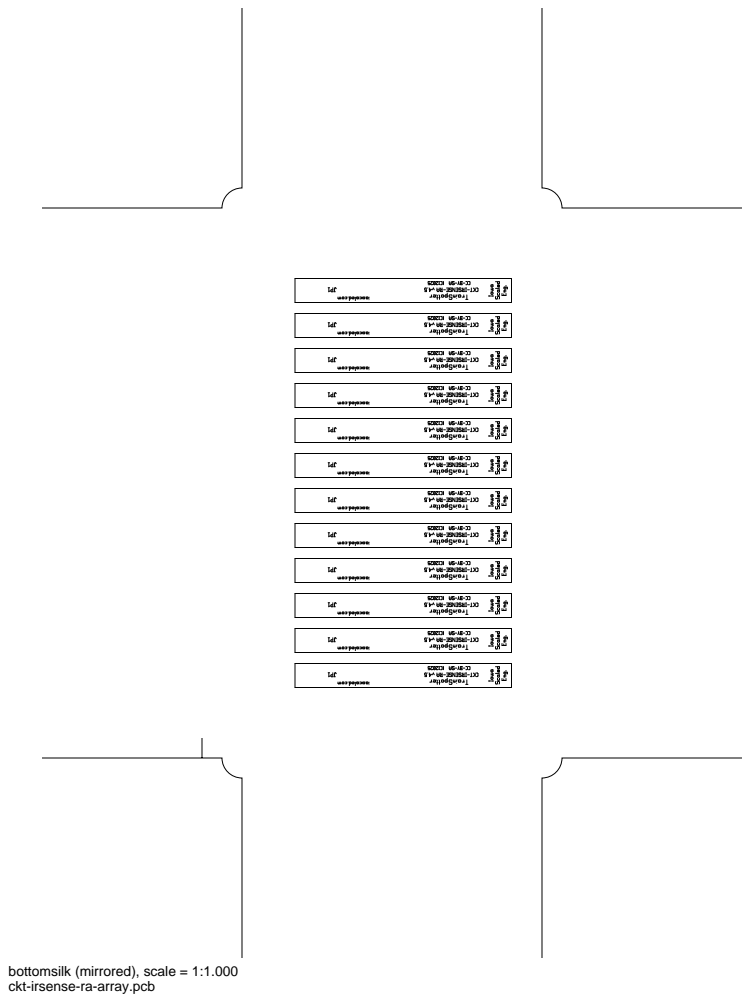
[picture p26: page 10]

bottomsilk (mirrored), scale = 1:1.000

toppaste, scale = 1:1.000 bottompaste (mirrored), scale = 1:1.000

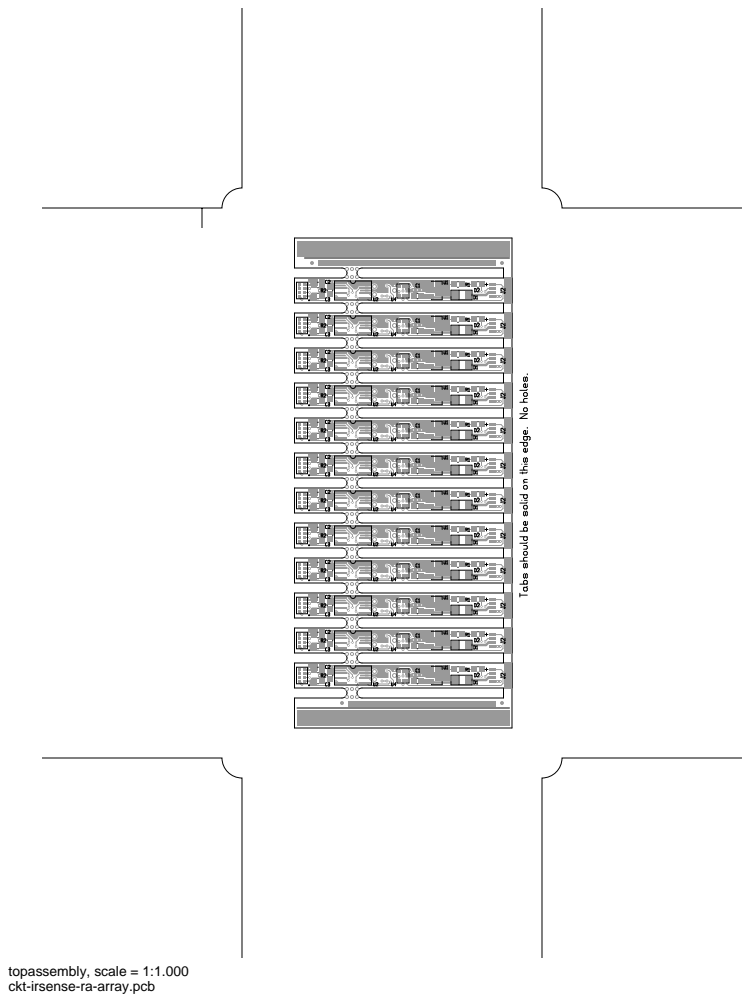
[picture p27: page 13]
topassembly, scale = 1:1.000


bottomassembly (mirrored), scale = 1:1.000

fab, scale = 1:1.000

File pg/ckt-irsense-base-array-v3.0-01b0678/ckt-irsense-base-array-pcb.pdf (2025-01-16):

# ckt-irsense-base-array.pcb

# 1. Table of Contents (This Page) Created on Sat Oct 15 21:50:19 2022

# 2. top 3. bottom 4. outline 5. plated-drill 6. unplated-drill 7. componentmask 8. soldermask 9. topsilk 10. bottomsilk 11. toppaste 12. topassembly 13. bottomassembly 14. fab

top, scale = 1:1.000


bottom (mirrored), scale = 1:1.000

outline, scale = 1:1.000


plated-drill, scale = 1:1.000


unplated-drill, scale = 1:1.000

topmask, scale = 1:1.000


bottommask (mirrored), scale = 1:1.000

topsilk, scale = 1:1.000


bottomsilk (mirrored), scale = 1:1.000

toppaste, scale = 1:1.000

topassembly, scale = 1:1.000


bottomassembly (mirrored), scale = 1:1.000

fab, scale = 1:1.000

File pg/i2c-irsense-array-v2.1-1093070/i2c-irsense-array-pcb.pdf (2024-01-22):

# i2c-irsense-array.pcb

# 1. Table of Contents (This Page) Created on Sun Jan 21 17:33:21 2024

# 2. top 3. bottom 4. outline 5. plated-drill 6. unplated-drill 7. componentmask 8. soldermask 9. topsilk 10. bottomsilk 11. toppaste 12. topassembly 13. bottomassembly 14. fab

top, scale = 1:1.000


bottom (mirrored), scale = 1:1.000

outline, scale = 1:1.000


plated-drill, scale = 1:1.000


unplated-drill, scale = 1:1.000

topmask, scale = 1:1.000

bottommask (mirrored), scale = 1:1.000

topsilk, scale = 1:1.000


bottomsilk (mirrored), scale = 1:1.000

toppaste, scale = 1:1.000

topassembly, scale = 1:1.000


bottomassembly (mirrored), scale = 1:1.000

fab, scale = 1:1.000

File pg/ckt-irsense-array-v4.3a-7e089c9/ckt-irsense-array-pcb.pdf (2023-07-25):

# ckt-irsense-array.pcb

# 1. Table of Contents (This Page) Created on Mon Jul 24 15:31:32 2023

# 2. top 3. bottom 4. outline 5. plated-drill 6. unplated-drill 7. componentmask 8. soldermask 9. topsilk 10. bottomsilk 11. toppaste 12. bottompaste 13. topassembly 14. bottomassembly 15. fab

top, scale = 1:1.000


bottom (mirrored), scale = 1:1.000

outline, scale = 1:1.000


plated-drill, scale = 1:1.000


unplated-drill, scale = 1:1.000

topmask, scale = 1:1.000


bottommask (mirrored), scale = 1:1.000

topsilk, scale = 1:1.000


bottomsilk (mirrored), scale = 1:1.000

toppaste, scale = 1:1.000 bottompaste (mirrored), scale = 1:1.000

topassembly, scale = 1:1.000


bottomassembly (mirrored), scale = 1:1.000

fab, scale = 1:1.000

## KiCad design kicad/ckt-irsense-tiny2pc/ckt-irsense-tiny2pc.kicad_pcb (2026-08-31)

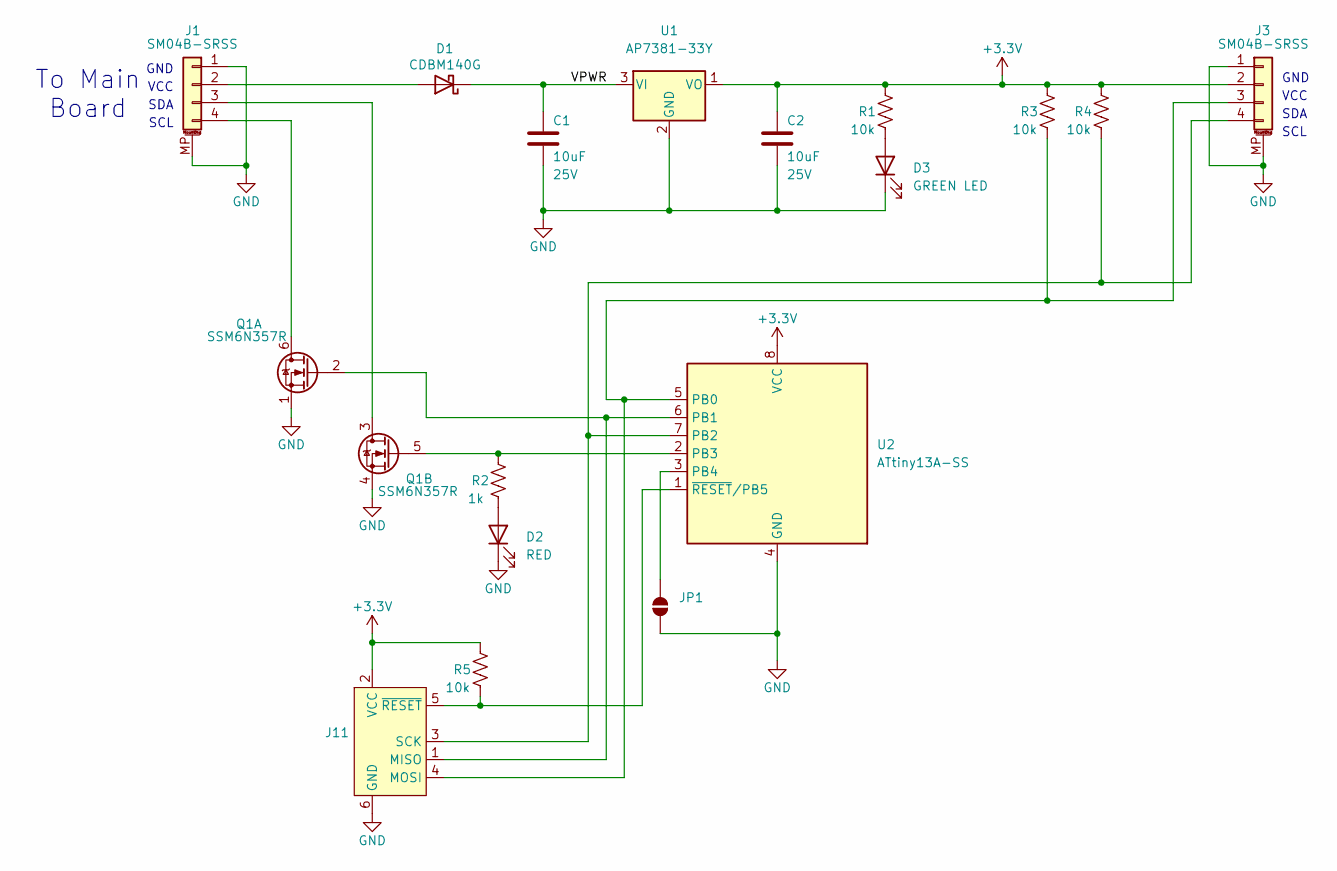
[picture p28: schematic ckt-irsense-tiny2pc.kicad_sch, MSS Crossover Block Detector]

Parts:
C1, C2: 10uF; C_0805_2012Metric; Voltage 25V
D1: CDBM140G; SOD-123T
D2: RED; LED_0805_2012Metric
D3: GREEN LED; LED_0805_2012Metric
J1, J3: SM04B-SRSS; JST_SH_SM04B-SRSS-TB_1x04-1MP_P1.00mm_Horizontal
J11: Conn_AVR_TagConnect_TC2030; Tag-Connect_TC2030-IDC-NL_2x03_P1.27mm_Vertical
JP1: SolderJumper_2_Open; SolderJumper-2_P1.3mm_Open_RoundedPad1.0x1.5mm
Q1: SSM6N357R; TSOP6F
R1, R3, R4, R5: 10k; R_0805_2012Metric
R2: 1k; R_0805_2012Metric
U1: AP7381-33Y; SOT-89-3
U2: ATtiny13A-SS; ATMEL_SO8_DUAL

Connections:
+3.3V: C2.1, J3.2, J11.2 (VCC), R1.2, R3.2, R4.2, R5.2, U1.1 (VO), U2.8 (VCC)
/VPWR: C1.1, D1.1 (K), U1.3 (VI)
GND: C1.2, C2.2, D2.1 (K), D3.1 (K), J1.1, J1.MP (MountPin), J3.1, J3.MP (MountPin), J11.6 (GND), JP1.1 (A), Q1.1 (S), Q1.4 (S), U1.2 (GND), U2.4 (GND)
unnamed: D1.2 (A), J1.2
unnamed: D2.2 (A), R2.1
unnamed: D3.2 (A), R1.1
unnamed: J1.3, Q1.3 (D)
unnamed: J1.4, Q1.6 (D)
unnamed: J11.1 (MISO), Q1.2 (G), U2.6 (PB1)
unnamed: J3.3, J11.4 (MOSI), R3.1, U2.5 (PB0)
unnamed: J3.4, J11.3 (SCK), R4.1, U2.7 (PB2)
unnamed: J11.5 (~RESET), R5.1, U2.1 (~RESET/PB5)
unnamed: JP1.2 (B), U2.3 (PB4)
unnamed: Q1.5 (G), R2.2, U2.2 (PB3)

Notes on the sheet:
GND
VCC
SCL
SDA
To Main Board

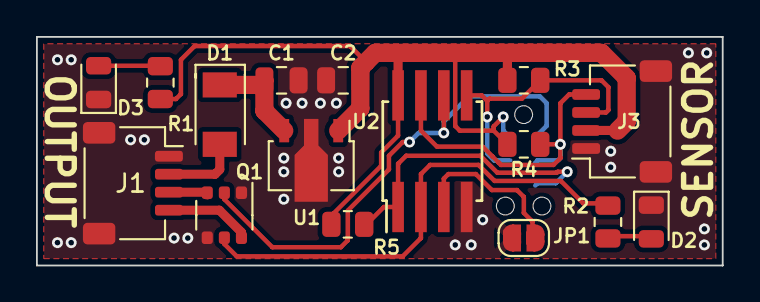
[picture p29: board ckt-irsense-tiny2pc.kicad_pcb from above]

Board: 2 copper layers, 38.1 x 12.7 mm, 17 parts (1 on the bottom side), 14 nets.

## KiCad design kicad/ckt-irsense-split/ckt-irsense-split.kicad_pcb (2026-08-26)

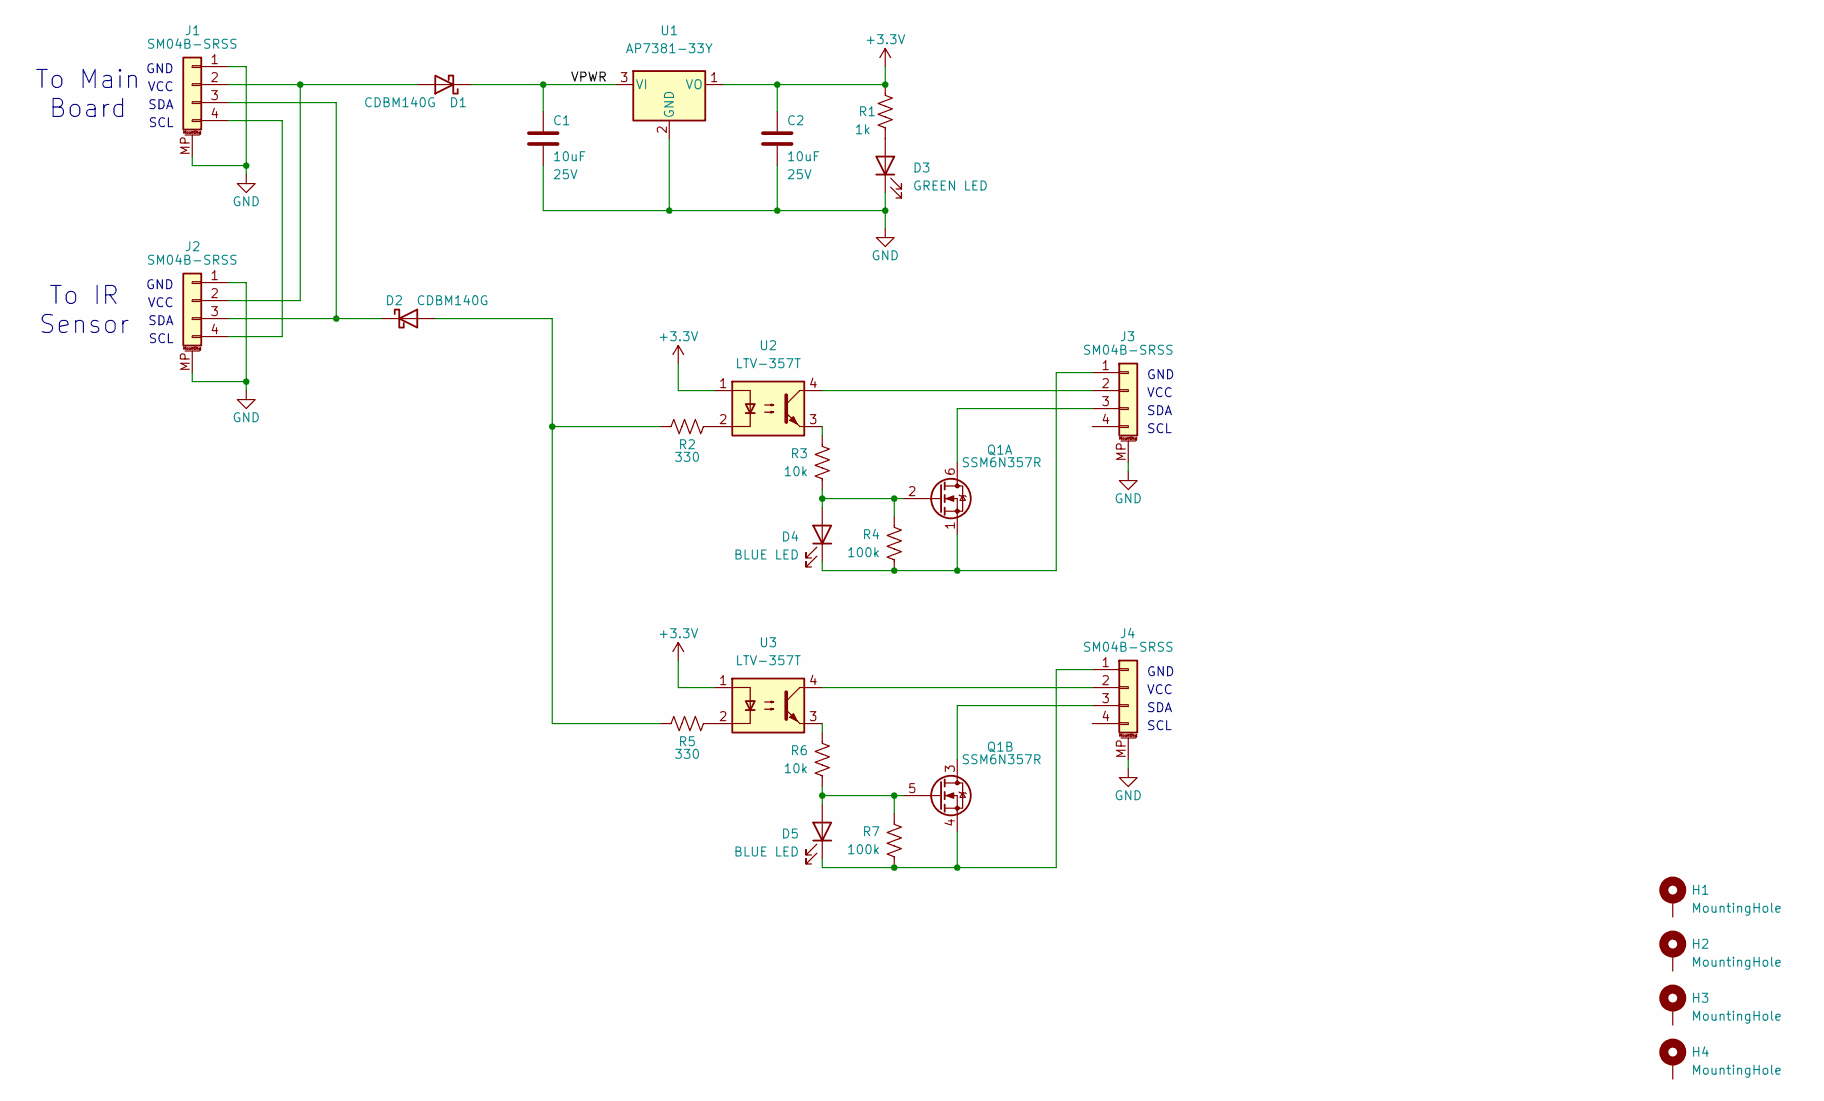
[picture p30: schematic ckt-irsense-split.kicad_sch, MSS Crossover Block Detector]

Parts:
C1, C2: 10uF; C_0805_2012Metric; Voltage 25V
D1, D2: CDBM140G; SOD-123T
D3: GREEN LED; LED_0805_2012Metric
D4, D5: BLUE LED; LED_0805_2012Metric
H1, H2, H3, H4: MountingHole; MountingHole_3.2mm_M3_Pad
J1, J2, J3, J4: SM04B-SRSS; JST_SH_SM04B-SRSS-TB_1x04-1MP_P1.00mm_Horizontal
Q1: SSM6N357R; TSOP6F
R1: 1k; R_0805_2012Metric
R2, R5: 330; R_0805_2012Metric
R3, R6: 10k; R_0805_2012Metric
R4, R7: 100k; R_0805_2012Metric
U1: AP7381-33Y; SOT-89-3
U2, U3: LTV-357T; SO-4_4.4x3.6mm_P2.54mm

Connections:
+3.3V: C2.1, R1.2, U1.1 (VO), U2.1, U3.1
/VPWR: C1.1, D1.1 (K), U1.3 (VI)
GND: C1.2, C2.2, D3.1 (K), J1.1, J1.MP (MountPin), J2.1, J2.MP (MountPin), J3.MP (MountPin), J4.MP (MountPin), U1.2 (GND)
unnamed: D1.2 (A), J1.2, J2.2
unnamed: D2.2 (A), R2.2, R5.2
unnamed: D2.1 (K), J1.3, J2.3
unnamed: D3.2 (A), R1.1
unnamed: D4.2 (A), Q1.2 (G), R3.1, R4.2
unnamed: D4.1 (K), J3.1, Q1.1 (S), R4.1
unnamed: D5.2 (A), Q1.5 (G), R6.1, R7.2
unnamed: D5.1 (K), J4.1, Q1.4 (S), R7.1
unnamed: J1.4, J2.4
unnamed: J3.2, U2.4
unnamed: J3.3, Q1.6 (D)
unnamed: J4.2, U3.4
unnamed: J4.3, Q1.3 (D)
unnamed: R2.1, U2.2
unnamed: R3.2, U2.3
unnamed: R5.1, U3.2
unnamed: R6.2, U3.3

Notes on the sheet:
SDA
GND
To IR Sensor
VCC
SCL
To Main Board

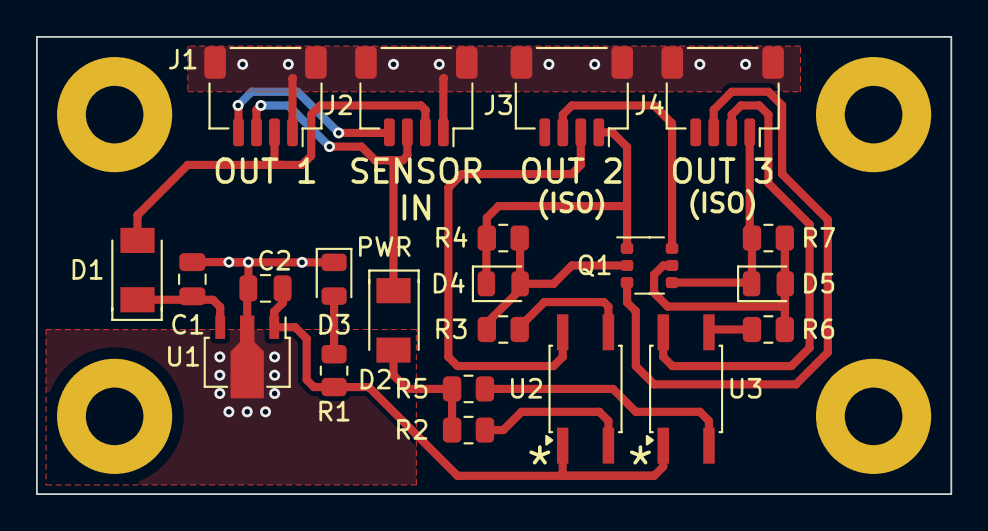
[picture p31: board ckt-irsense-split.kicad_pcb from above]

Board: 2 copper layers, 50.8 x 25.4 mm, 26 parts (0 on the bottom side), 20 nets.

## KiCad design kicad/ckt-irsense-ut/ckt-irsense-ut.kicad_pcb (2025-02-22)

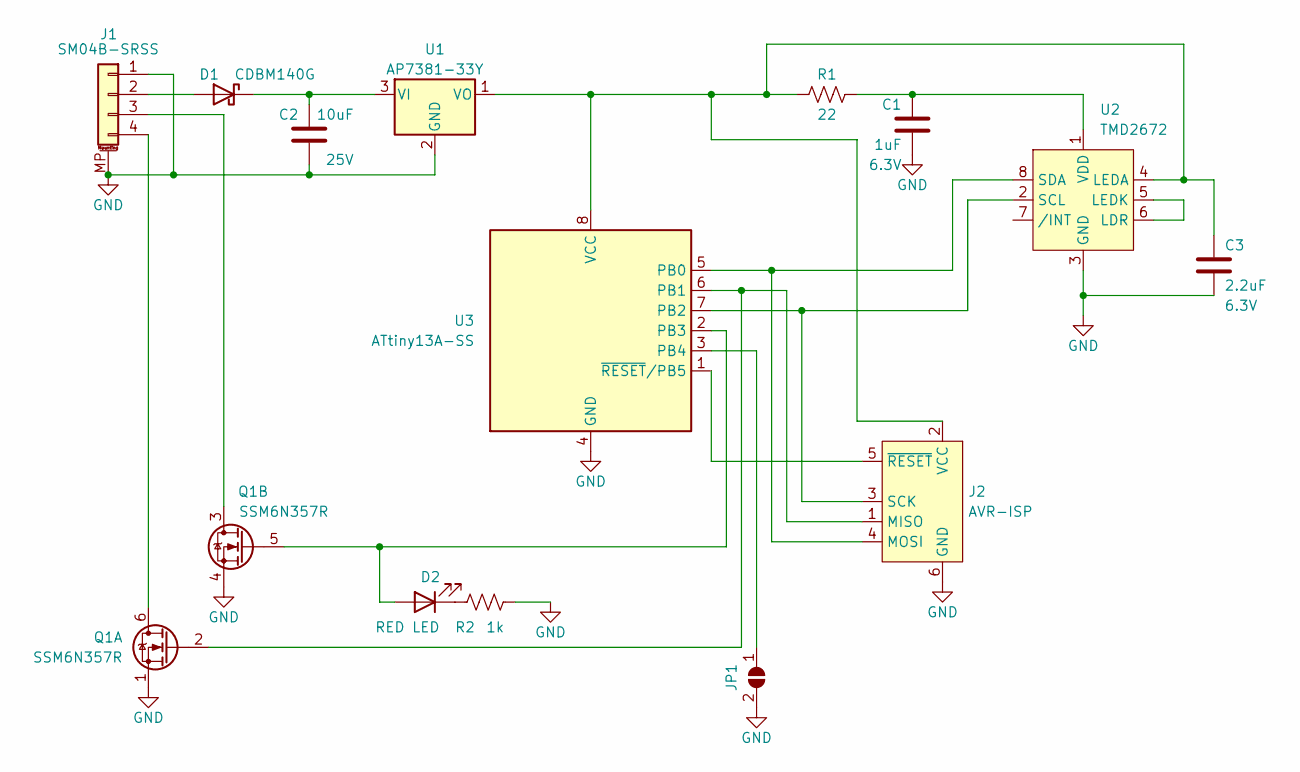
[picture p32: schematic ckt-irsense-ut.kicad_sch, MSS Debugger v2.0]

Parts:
C1: 1uF; C_0805_2012Metric; Voltage 6.3V
C2: 10uF; C_0805_2012Metric; Voltage 25V
C3: 2.2uF; C_0805_2012Metric; Voltage 6.3V
D1: CDBM140G; SOD-123T
D2: RED LED; LED_0805_2012Metric
J1: SM04B-SRSS; JST_SH_SM04B-SRSS-TB_1x04-1MP_P1.00mm_Horizontal
J2: AVR-ISP; Tag-Connect_TC2030-IDC-NL_2x03_P1.27mm_Vertical
JP1: SolderJumper_2_Open; SolderJumper-2_P1.3mm_Open_RoundedPad1.0x1.5mm
Q1: SSM6N357R; TSOP6F
R1: 22; R_0805_2012Metric
R2: 1k; R_0805_2012Metric
U1: AP7381-33Y; SOT-89-3
U2: TMD2672
U3: ATtiny13A-SS; SOIC-8_3.9x4.9mm_P1.27mm

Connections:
GND: C1.2, C2.2, C3.2, J1.1, J1.MP (MountPin), J2.6 (GND), JP1.2 (B), Q1.1 (S), Q1.4 (S), R2.1, U1.2 (GND), U2.3 (GND), U3.4 (GND)
unnamed: C1.1, R1.1, U2.1 (VDD)
unnamed: C2.1, D1.1 (K), U1.3 (VI)
unnamed: C3.1, J2.2 (VCC), R1.2, U1.1 (VO), U2.4 (LEDA), U3.8 (VCC)
unnamed: D1.2 (A), J1.2
unnamed: D2.1 (K), R2.2
unnamed: D2.2 (A), Q1.5 (G), U3.2 (PB3)
unnamed: J1.3, Q1.3 (D)
unnamed: J1.4, Q1.6 (D)
unnamed: J2.1 (MISO), Q1.2 (G), U3.6 (PB1)
unnamed: J2.3 (SCK), U2.2 (SCL), U3.7 (PB2)
unnamed: J2.4 (MOSI), U2.8 (SDA), U3.5 (PB0)
unnamed: J2.5 (~RESET), U3.1 (~RESET/PB5)
unnamed: JP1.1 (A), U3.3 (PB4)
unnamed: U2.5 (LEDK), U2.6 (LDR)

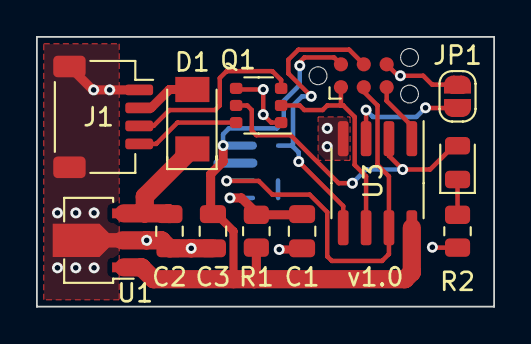
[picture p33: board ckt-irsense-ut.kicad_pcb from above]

Board: 2 copper layers, 25.4 x 15.0 mm, 14 parts (1 on the bottom side), 15 nets.

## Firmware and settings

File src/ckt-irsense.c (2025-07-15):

/*************************************************************************
Title:    IR reflective sensor v3.1
Authors:  Michael Petersen <railfan@drgw.net>
          Nathan D. Holmes <maverick@drgw.net>
File:     $Id: $
License:  GNU General Public License v3

LICENSE:
    Copyright (C) 2014 Michael Petersen & Nathan Holmes

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
*************************************************************************/

#include <stdlib.h>
#include <stdbool.h>
#include <avr/io.h>
#include <avr/interrupt.h>
#include <avr/wdt.h>
#include <util/delay.h>
#include <avr/eeprom.h>


#define   TMD267x1_ADDR   0x39
#define   INFO_ADDR       0x20

#define   PROXIMITY_THRESHOLD_DEFAULT     0x300
#define   SENSOR_ERROR_THRESHOLD  0
#define   PPULSE_DEFAULT          8

#define   ON_DEBOUNCE_DEFAULT   1

#define   SDA   PB0
#define   SCL   PB2

static inline void sda_low() { DDRB |= _BV(SDA); PORTB &= ~_BV(SDA); _delay_us(10); }
static inline void sda_high() { DDRB &= ~_BV(SDA); PORTB |= _BV(SDA); _delay_us(10); }
static inline void scl_low() { PORTB &= ~_BV(SCL); _delay_us(10); }
static inline void scl_high() { PORTB |= _BV(SCL); _delay_us(10); }

volatile uint8_t ticks;
volatile uint8_t decisecs = 0;

void initialize100HzTimer(void)
{
	// Set up timer 0 for 100Hz interrupts
	TCNT0 = 0;
	OCR0A = 94;  // 9.6MHz / 1024 / 94 = 100Hz
	ticks = 0;
	decisecs = 0;
	TCCR0A = _BV(WGM01);
	TCCR0B = _BV(CS02) | _BV(CS00);  // 1024 prescaler
	TIMSK0 |= _BV(OCIE0A);
}

ISR(TIM0_COMPA_vect)
{
	if (++ticks >= 10)
	{
		ticks = 0;
		decisecs++;
	}
}

void i2cStart(void)
{
	scl_high();
	sda_low();
	scl_low();
	sda_high();
}

void i2cStop(void)
{
	scl_low();
	sda_low();
	scl_high();
	sda_high();
}

uint8_t i2cWriteByte(uint8_t byte)
{
	uint8_t i = 0x80, ack;

	do
	{
		if(byte & i)
		{
			sda_high();
		}
		else
		{
			sda_low();
		}
		
		scl_high();
		scl_low();
		
		i >>= 1;
	} while(i);

	sda_high();  // Release SDA
	
	scl_high();
	if(PINB & _BV(SDA))
		ack = 0;
	else
		ack = 1;
	scl_low();

	return ack;
}

uint8_t i2cReadByte(uint8_t ack)
{
	uint8_t i, data = 0;

	for(i=0; i<8; i++)
	{
		data = data << 1;
		scl_high();
		if(PINB & _BV(SDA))
			data |= 0x01;
		scl_low();
	}
	
	if(ack)
		sda_low();
	scl_high();
	scl_low();
	sda_high();

	return data;
}

uint8_t writeByte(uint8_t addr, uint8_t cmd, uint16_t writeVal)
{
	uint8_t ack;
	
	i2cStart();
	
	i2cWriteByte(addr << 1);
	i2cWriteByte(cmd);
	ack = i2cWriteByte(writeVal);

	i2cStop();

	return ack;
}

uint8_t readWord(uint8_t addr, uint8_t cmd, uint16_t* data)
{
	uint8_t ack = 1;
	*data = 0xFFFF;
	
	i2cStart();
	
	ack &= i2cWriteByte(addr << 1);
	ack &= i2cWriteByte(cmd);

	i2cStart();

	ack &= i2cWriteByte((addr << 1) | 0x01);
	*data = i2cReadByte(1);
	*data |= ((uint16_t)i2cReadByte(0) << 8);
	
	i2cStop();

	return ack;
}

void init(void)
{
	MCUSR = 0;
	wdt_reset();
	wdt_enable(WDTO_250MS);
	wdt_reset();

	// Configure ADC
	ADMUX = 0x02;  // ref = VCC, right-justified, input = PB4 (ADC2)
	ADCSRA = 0x87; // ADC enabled, prescaler = 128
	DIDR0 = _BV(ADC2D);  // Disable ADC2 digital input buffer
	
	PORTB = _BV(SCL) | _BV(PB1);  // All outputs low except SCL and PB1
	DDRB |= _BV(PB1) | _BV(SCL) | _BV(PB3);
	
#ifndef TWOPIECE
	// Enable internal pull-up on ADJ pin
	DDRB &= ~_BV(PB4);
	PORTB |= _BV(PB4);
#endif
}

#define TMD26711_ID_VALUE 0x20
#define TMD26713_ID_VALUE 0x29
#define TMD26721_ID_VALUE 0x32
#define TMD26723_ID_VALUE 0x38

void initializeTMD267x1()
{
	uint16_t i=0;
	uint8_t isTMD2671x = 0;
	
	// Initialize TMD267x1 (bit 0x80 set to indicate command)
	writeByte(TMD267x1_ADDR, 0x80|0x00, 0x00);   // Start with everything disabled
	writeByte(TMD267x1_ADDR, 0x80|0x01, 0xFF);   // Minimum ATIME
	writeByte(TMD267x1_ADDR, 0x80|0x02, 0xFF);   // Maximum integration time
	writeByte(TMD267x1_ADDR, 0x80|0x03, 0xFF);   // Minimum wait time

	if (readWord(TMD267x1_ADDR, 0x80|0x20|0x12, &i))
	{
		if ((i & 0xFF) < TMD26721_ID_VALUE) // Also applies for TMD277xx, same IDs
			isTMD2671x = 1;
	}
	
	// Note: IRQ not currently used
	writeByte(TMD267x1_ADDR, 0x80|0x08, 0x00);   // Set interrupt low threshold to 0x0000
	writeByte(TMD267x1_ADDR, 0x80|0x09, 0x00);
	writeByte(TMD267x1_ADDR, 0x80|0x0A, 0x00);   // Set interrupt low threshold to 0x0300
	writeByte(TMD267x1_ADDR, 0x80|0x0B, 0x03);
	writeByte(TMD267x1_ADDR, 0x80|0x0C, 0x10);   // Single out-of-range cycle triggers interrupt

	writeByte(TMD267x1_ADDR, 0x80|0x0D, 0x00);   // Long wait disabled
	writeByte(TMD267x1_ADDR, 0x80|0x0E, PPULSE_DEFAULT); // Pulse count

	writeByte(TMD267x1_ADDR, 0x80|0x0F, isTMD2671x?0x20:0x28);   // 100% LED drive strength, Use channel 1 diode (ch 1 seems less sensitive to fluorescent light) - TMD26711
	writeByte(TMD267x1_ADDR, 0x80|0x00, 0x27);   // Power ON, Enable proximity, Enable proximity interrupt (not used currently)
}

void setOutputs(bool detect)
{
#ifdef DOUBLEOUTPUT
	// In this mode, both outputs are active if detection, inactive otherwise
	// Useful for MSS-type setups
	if(detect)
	{
		PORTB |= _BV(PB3) | _BV(PB1);
	}
	else
	{
		PORTB &= ~(_BV(PB3) | _BV(PB1));
	}

#elif defined PULSE_OUTPUT
	static bool prev_detect = false;
	if (prev_detect != detect)
	{
		if (prev_detect)
			PORTB |= _BV(PB1);
		else
			PORTB |= _BV(PB3);
	} else {
		PORTB &= ~(_BV(PB3) | _BV(PB1));
	}
	prev_detect = detect;

	
#else
	if(detect)
	{
		PORTB |= _BV(PB3);
		PORTB &= ~_BV(PB1);
	}
	else
	{
		PORTB &= ~_BV(PB3);
		PORTB |= _BV(PB1);
	}
#endif

}

int main(void)
{
#ifdef TWOPIECE
	//  Two Piece Specific Setup
	uint16_t proximity_threshold = PROXIMITY_THRESHOLD_DEFAULT;
	uint16_t count = 0;  // 256 decisecs * 60 (long delay mode) = 15360 max count
	int16_t on_debounce, off_debounce;  // Signed so the math for off_debounce doesn't wrap
#else
	//  One Piece Specific Setup
	uint16_t proximity_threshold = (eeprom_read_byte((const uint8_t *)0x00) << 8) + eeprom_read_byte((const uint8_t *)0x01);
	if(0xFFFF == proximity_threshold)
		proximity_threshold = PROXIMITY_THRESHOLD_DEFAULT;
	uint8_t count = 0;
	int8_t on_debounce, off_debounce;
#endif
	uint16_t proximity;
	bool detect = false;
	uint8_t sensorError = 0;
//	uint8_t ppulse;
	uint8_t ack;
	int16_t adc, adc_filt = 0;
	
	// Application initialization
	init();
	initialize100HzTimer();
	sei();

	initializeTMD267x1();


	while (1)
	{
		wdt_reset();

		if(decisecs >= 1)
		{
			decisecs = 0;
//			ppulse = PPULSE_DEFAULT;
//			writeByte(TMD267x1_ADDR, 0x80|0x0E, ppulse);

			// Read ADC
			ADCSRA |= _BV(ADSC);  // Trigger conversion
			while(ADCSRA & _BV(ADSC));
			adc = ADC;
			adc_filt = adc_filt + ((adc - adc_filt) / 4);

			on_debounce = ON_DEBOUNCE_DEFAULT;
#ifdef TWOPIECE
			off_debounce = ((1023 - adc_filt) - 100 + 2) / 4;  // Invert, shift, divide-by-4, round
			if(off_debounce < 1)
				off_debounce = 1;  // Limit to 1
#else
			off_debounce = (adc_filt > 512) ? 0 : RELEASE_DECISECS;
#endif

#ifdef LONG_DELAY
			off_debounce *= 64;
#endif
			// Telemetry
//			writeByte(INFO_ADDR, adc_filt >> 8, adc_filt & 0xFF);

			if (sensorError)
			{
				initializeTMD267x1();
			}	

			ack = readWord(TMD267x1_ADDR, 0x80|0x20|0x18, &proximity);  // Read data register (0x80 = command, 0x20 = auto-increment)

			if (!ack)
			{
				// Sensor's gone wonky, reset it and try again
				if (sensorError < 255)
					sensorError++;

				if (sensorError > SENSOR_ERROR_THRESHOLD)
				{
					detect = false;
					proximity = 0;
					count = 0;
					setOutputs(detect);
				}

				continue;

			} else {
				sensorError = 0;
			}

			if(!detect & (proximity >= proximity_threshold))
			{
				// ON debounce
				count++;
				if(count > on_debounce)
				{
					detect = true;
					count = 0;
				}
			}
			else if(!detect & (proximity < proximity_threshold))
			{
				count = 0;
			}

			else if(detect & (proximity < proximity_threshold))
			{
				// OFF debounce
				count++;
				if(count > off_debounce)
				{
					detect = false;
					count = 0;
				}
			}
			else if(detect & (proximity >= proximity_threshold))
			{
				count = 0;
			}
			setOutputs(detect);

		}

	}
}

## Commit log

2014-01-02 Initial cut of IR sensor stuff
    [ckt-irsense.sch]
2014-01-02 More updates, changed pin assignments
    [ckt-irsense.sch]
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2014-01-02 Not done yet, but betterish
    [ckt-irsense.sch]
2014-01-10 Updated irsense schematic, hopefully ready to start on PCB except for programming header
    [ckt-irsense.sch]
2014-01-10 Add 5-turn trimmer footprint Update footprint on schematic
    [ckt-irsense.sch]
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2014-01-20 Schematic updates to make the pcb go together right
    [ckt-irsense.sch]
2014-01-22 Update voltage on input cap
    [ckt-irsense.sch]
2014-01-22 Fix for J1 soldermask clearance
2014-01-22 Change attiny to wide tssop8 footprint
    [ckt-irsense.sch]
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2014-01-22 More updates - fix footprint for Vishay VSOP
    [ckt-irsense.sch]
2014-01-22 Fixes to the irsense PCB to get 6/6 DRC on new VSOP part Add text to output pins and + on diodes
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2014-02-23 No idea where my first pg went, but this should be identical
    [ckt-irsense.bottom.gbr, ckt-irsense.bottommask.gbr, ckt-irsense.bottompaste.gbr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]
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2014-03-22 OSHPark order on 3/22/2014
    [ckt-irsense.bottom.gbr, ckt-irsense.bottommask.gbr, ckt-irsense.bottompaste.gbr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]
2014-05-12 Swapped IR diode and LED Added Q1 to cost sheet
    [ckt-irsense.sch]
2014-06-13 New version using integrated IR sensor module
    [ckt-irsense.sch]
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2014-06-13 Miserable failure at reducing size... tired. Going to bed.
    [ckt-irsense.sch]
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2014-06-22 Changed to local connector footprint
    [ckt-irsense.sch]
2014-06-22 Sent to OSH on 6/13/2014
    [ckt-irsense.bottom.gbr, ckt-irsense.bottommask.gbr, ckt-irsense.bottompaste.gbr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]
2014-06-22 Changed 22uF cap from 16V to 6.3V
    [ckt-irsense.sch]
2014-06-24 Sent to OSH 6/23
    [ckt-irsense-sns-panel.bottom.gbr, ckt-irsense-sns-panel.bottommask.gbr, ckt-irsense-sns-panel.bottompaste.gbr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]
2014-06-30 Added ADC for PPULSE
    [adc.xls]
2014-06-30 Was open when checked in last...
    [adc.xls]
2014-07-27 Updated tables for variable delay
    [adc.xls]
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2014-07-30 Added sense distances Updated applications
    [usermanual.sch]
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2014-09-26 Fixed spring switch diagram text
2014-09-26 Fixed spring switch diagram wire z-axis
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2015-02-02 Added panel of boards. Renamed oshpark gerbers.
    [ckt-irsense-panel.bottom.gbr, ckt-irsense-panel.bottommask.gbr, ckt-irsense-panel.bottompaste.gbr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]
2015-02-28 Add i2c-irsense - a modified version of the body that passes the I2C lines through so that multiple heads can be connected to one micro
    [i2c-irsense.sch]
2015-06-23 Modify i2c breakout for irsense
    [i2c-irsense.sch]
2015-06-24 Add first cut of a I2C-IRSENSE board
    [i2c-irsense.sch]
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2015-10-16 New idea for the i2c-irsense
    [i2c-irsense.sch]
2015-10-16 Initial cut of a possible separate CKT-IRSENSE with sensor and base
    [ckt-irsense-base.sch]
2015-10-17 Fixed text alignment
    [ckt-irsense-base.sch]
2015-10-26 Update base to include 100k pot for delay adjust Update .gitignore to ignore intermediate gsch2pcb files
    [ckt-irsense-base.sch]
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2015-11-02 PG out the i2c-irsense
    [i2c-irsense.bottom.gbr, i2c-irsense.bottommask.gbr, i2c-irsense.bottompaste.gbr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]
2015-11-02 Add pg 1.0 of the irsense base unit
    [ckt-irsense-base.bottom.gbr, ckt-irsense-base.bottommask.gbr, ckt-irsense-base.bottompaste.gbr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]
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2016-01-26 New irsense stalk with large pads for direct solder
    [i2c-irsense.sch]
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2016-01-30 Sent to fab 1/29/2016
    [test-irsense.bottom.gbr, test-irsense.bottommask.gbr, test-irsense.bottompaste.gbr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]
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2016-03-08 Add preliminary error handling. Needs more thought tomorrow.
    [ckt-irsense.c]
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2016-12-13 Sent to fab 12/12/2016
    [test-irsense.bottom.gbr, test-irsense.bottommask.gbr, test-irsense.bottompaste.gbr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]
2017-03-07 Smaller paste on AVR
    [ckt-irsense-panel.toppaste.gbr]
2017-12-12 I2C version with SH connector (and panel)
    [i2c-irsense.sch]
2018-01-03 Sent to fab 1/2/2018
    [i2c-irsense-panel.bottom.gbr, i2c-irsense-panel.bottommask.gbr, i2c-irsense-panel.bottompaste.gbr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]
2018-01-06 Schematic for Qwiic version
    [i2c-irsense.sch]
2018-01-06 Added label to symbol
    [i2c-irsense.sch]
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2018-01-29 Sent to fab v2.1
    [i2c-irsense-panel.bottom.gbr, i2c-irsense-panel.bottommask.gbr, i2c-irsense-panel.bottompaste.gbr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]
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2018-04-29 Sent to fab 4/28/2018
    [ckt-irsense-base.bottom.gbr, ckt-irsense-base.bottommask.gbr, ckt-irsense-base.bottompaste.gbr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]
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2020-07-02 v4 Changes: Removed Rpack Added JP1 Removed 22uF regulator and AVR caps Changed sensor cap to 2.2uF Changed LED to 0805 Changed input diode to CDBM140G Added J2
    [ckt-irsense.sch]
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2020-07-02 Added copper to JST mounting pads, fixed some metal planes, added website.
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2020-07-04 Sent to fab 7/2
    [ckt-irsense-panel.bottom.gbr, ckt-irsense-panel.bottommask.gbr, ckt-irsense-panel.bottompaste.gbr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]
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2020-07-17 Fixed title block (v3 -> v4)
    [ckt-irsense.sch]
2020-08-02 Version 4 with ATtiny13A
    [ckt-irsense.sch]
2020-08-08 Added fixed 3s delay for 1pc version and options for 2pc.
    [ckt-irsense.c]
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2020-08-20 Sent to fab 8/19
    [ckt-irsense-panel.bottom.gbr, ckt-irsense-panel.bottommask.gbr, ckt-irsense-panel.bottompaste.gbr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]
2020-09-27 v2 of the ckt-irsense-base to convert to an attiny13a
    [ckt-irsense-base.sch]
2020-09-27 Fixed J2 GND text
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2020-10-18 Sent to fab 10/2020
    [ckt-irsense-ra.bottom.gbr, ckt-irsense-ra.bottommask.gbr, ckt-irsense-ra.bottompaste.gbr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]
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2020-10-26 Rearranged user manual files
    [usermanual.sch]
2020-12-27 Sent to fab (additional notes)
    [ckt-irsense-panel.bottom.gbr, ckt-irsense-panel.bottommask.gbr, ckt-irsense-panel.bottompaste.gbr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]
2021-02-25 Fab files with fab text
    [i2c-irsense-panel.bottom.gbr, i2c-irsense-panel.bottommask.gbr, i2c-irsense-panel.bottompaste.gbr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]
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2022-04-08 Make the 2pc code fit with autodetect Does NOT include long delay, which does not fit
    [ckt-irsense.c]
2022-05-12 Added 8S2 footprint and moved C2/prog header 10mils away (and associated wiring)
    [ckt-irsense.sch]
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2022-05-12 Swapped template and pcb file
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2022-10-16 Update 2pc base to get rid of the RJ and go to discrete resistors
    [ckt-irsense-base.sch]
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2023-02-02 Fixed version number
    [ckt-irsense-sns-panel-3x.bottom.gbr, ckt-irsense-sns-panel-3x.bottommask.gbr, ckt-irsense-sns-panel-3x.bottompaste.gbr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]
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2024-12-31 v4.4 Fixed connector metal Changed to TSOP6F footprint
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2026-08-23 Updates to fix some minor DRCs
    [ckt-irsense-split.kicad_pcb]
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

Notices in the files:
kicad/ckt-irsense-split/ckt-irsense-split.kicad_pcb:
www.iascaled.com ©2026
